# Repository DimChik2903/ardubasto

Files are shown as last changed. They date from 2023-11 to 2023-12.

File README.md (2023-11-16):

# Ardubasto: GSM/GPRS контроллер для предпусковых подогревателей с управлением по SMS и MQTT

**Автор проекта – [MaksVV](https://forum.arduino.ru/u/maksvv/) с форума arduino.ru**

[Чат в Telegram](https://t.me/ardubasto)

[Оригинальная тема](https://forum.arduino.ru/t/gsm-ustrojstvo-upravleniya-kotlami-webasto-i-ne-tolko/9851) на форуме forum.arduino.ru *При необходимости: [старая тема](https://arduino.ru/forum/proekty/gsm-ustroistvo-upravleniya-kotlami-webasto-i-ne-tolko)*

## Внимание! Репозиторий находится в разработке!

## [Основной Wiki](https://github.com/DimChik2903/ardubasto/wiki)

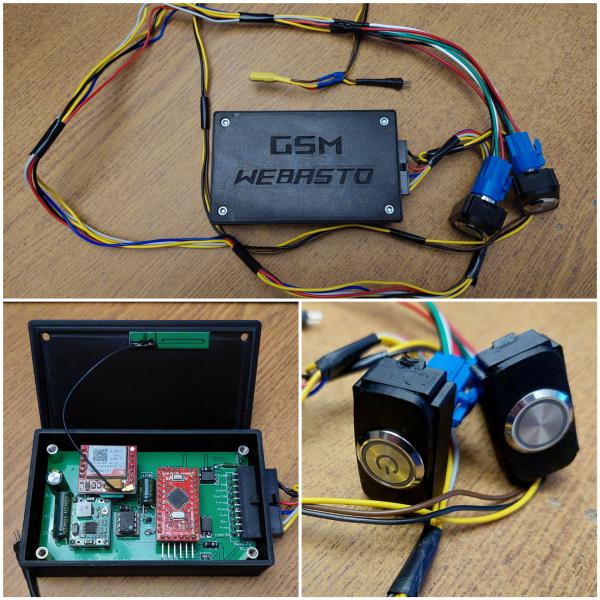
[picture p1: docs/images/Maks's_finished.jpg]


## Об устройстве
### Совместимость

* Запуск по потенциалу +12В (Webasto Thermo Top C/E)
* Запуск импульсом GND 1 сек (Webasto Thermo Top C/E)
* Запуск по шине W-Bus (Webasto Thermo Top C/E, Thermo Top Evo)
* Запуск по шине Eberspacher Hydronic

### Основные функции

* Запуск/останов котла
* Информация об ошибках
* Информация об основных параметрах котла
* Дополнительные внешние датчики температуры авто
* Работа с сигнализацеий (автозапуск)

## Быстрый старт

 [1. Закажи компоненты](https://github.com/DimChik2903/ardubasto/wiki/%D0%97%D0%B0%D0%BA%D0%B0%D0%B7-%D0%BA%D0%BE%D0%BC%D0%BF%D0%BE%D0%BD%D0%B5%D0%BD%D1%82%D0%BE%D0%B2)

 [2. Собери устройство](https://github.com/DimChik2903/ardubasto/wiki/%D0%A1%D0%B1%D0%BE%D1%80%D0%BA%D0%B0-%D1%83%D1%81%D1%82%D1%80%D0%BE%D0%B9%D1%81%D1%82%D0%B2%D0%B0)

 [3. Прошей](https://github.com/DimChik2903/ardubasto/wiki/%D0%9F%D1%80%D0%BE%D1%88%D0%B8%D0%B2%D0%BA%D0%B0)

 [4. Подключи](https://github.com/DimChik2903/ardubasto/wiki/%D0%9F%D0%BE%D0%B4%D0%BA%D0%BB%D1%8E%D1%87%D0%B5%D0%BD%D0%B8%D0%B5)

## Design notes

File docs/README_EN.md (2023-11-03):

# Ardubasto: GSM/GPRS контроллер для предпусковых подогревателей с управлением по SMS и MQTT

[English version](#ardubasto-gsmgprs-controller-for-parking-heaters-with-sms-control-and-mqtt-support)

**Автор проекта – [MaksVV](https://forum.arduino.ru/u/maksvv/) с форума arduino.ru**

[Чат в Telegram](https://t.me/ardubasto)

[Оригинальная тема](https://forum.arduino.ru/t/gsm-ustrojstvo-upravleniya-kotlami-webasto-i-ne-tolko/9851) на форуме forum.arduino.ru *При необходимости: [старая тема](https://arduino.ru/forum/proekty/gsm-ustroistvo-upravleniya-kotlami-webasto-i-ne-tolko)*

## Внимание! Репозиторий находится в разработке!

**[Основной Wiki](https://github.com/DimChik2903/ardubasto/wiki)**

## Об устройстве
### Совместимость

* Запуск по потенциалу +12В (Webasto Thermo Top C/E)
* Запуск импульсом GND 1 сек (Webasto Thermo Top C/E)
* Запуск по шине W-Bus (Webasto Thermo Top C/E)
* Запуск по шине W-Bus (Webasto Thermo Top Evo)
* Запуск по шине Бинар (?)

### Основные функции

* Запуск/останов котла
* Информация об ошибках
* Информация об основных параметрах котла
* Дополнительные внешние датчики температуры авто
* Работа с сигнализацеий (автозапуск)

## Быстрый старт

1) Заказать компоненты
2) Спаять плату
3) Прошить [eeprom](https://github.com/DimChik2903/ardubasto/tree/main/software/firmware) (eeprom)
4) Прошить [актуальную прошивку](https://github.com/DimChik2903/ardubasto/tree/main/software/firmware) (main_firmware)

# Ardubasto: GSM/GPRS controller for parking heaters with SMS control and MQTT support

**Project Author – MaksVV from arduino.ru forum**

## Attention! We are currently working on the repository!

[Wiki](https://github.com/DimChik2903/ardubasto/wiki) (In Russian)

## Fast start

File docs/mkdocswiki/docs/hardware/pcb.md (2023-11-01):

# Сборка

## Совместимость

* Запуск по потенциалу +12В (Webasto Thermo Top C/E)
* Запуск импульсом GND 1 сек (Webasto Thermo Top C/E)
* Запуск по шине W-Bus (Webasto Thermo Top Evo C)
* Запуск по шине Бинар

## Основные функции

* Запуск/останов котла
* Информация по ошибкам

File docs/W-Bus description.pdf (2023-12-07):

Описание протокола W-Bus

Supplementary heater – догреватель (предусмотрена работа только при запущенном двигателе) Auxiliary heater – догреватель
Parking heater - предпусковой подогреватель

Изменения от: 2011-01-05 (year-month-day)
Это все догадки, основанные на внешнем изучении протокола W-Bus. Никакой декомпиляции бинарников или чего то подобного не делалось.
W-Bus схематически идентичен интерфейсу OBD II. Он работает используя последовательный порт с открытым коллектором на скорости 2400 бод в формате 8E1 (с проверкой четности-even parity)

Распиновка разъемов Thermo Top V heater

8-pin разъем
Pin 1: On/Off предположительно, но не работает.

Pin 2: W-Bus (диагностика или Webasto 1533 таймер)
Pin 3: Предположительно датчик температуры для догревателя (supplemental heater)(импульсное управление «-»)
Pin 4: CAN low
Pin 5: Дозирующий топливный насос
Pin 6: Электромагнитный клапан для переключения циркуляции ОЖ Pin 7: CAN high
Pin 8: Выход управления вентилятором отопителя салона

2-pin разъем
Pin 1: +12 питания
Pin 2: Масса

3-pin разъем
Pin 1: no idea
Pin 2: +12 циркуляционной помпы Pin 3: Масса циркуляционной помпы

Примечания:
Все (большинство) числа в шестнадцатеричном виде
Поскольку RX и TX линии подключены к одной точке, все переданные данные возвращаются в передатчик Since rx and tx lines are connected together to a single wire, all
transmissions are echoed back to the transmitter.

Инициализация

//В другой документации было указано, что необходимо подать сначала логическую 1 на 25мс, а //потом логический 0 на 25мс, или наоборот.

BREAK set for 50ms
BREAK reset and wait 50ms
После этого происходит следующая передача данных, WTT опрашивает котел (функционал и идентификационные данные)

TX f4 03 51 0a ac
RX 4f 04 d1 0a 33 a3
TX f4 03 51 0b ad
RX 4f 0b d1 0b 50 51 33 35 20 53 48 20 82 TX f4 03 51 0c aa
RX 4f 0a d1 0c 71 7c c4 e7 3f 80 00 09 TX f4 02 38 ce
RX 4f 09 b8 0b 00 00 00 00 03 dd 2b

Нагреватель не отвечает без последовательности пауз (прерываний). Но не совсем понятно с какой

целью это происходит.

Протокол W-Bus основан на пакетной передаче. Передача данных это всегда сформированный пакет, с адресом, длиной, командой и контрольной суммой. Базовая структура такая:

Header, length, command, data, checksum
Заголовок, длина, команда, данные (для выполнения команды-?), контрольная сумма

Заголовок:
Включает один байт. Каждый полубайт это 4 бита адреса устройства. Высший полубайт это адрес отправителя, низший полубайт адрес получателя.
Адрес Thermo Top V heater - 4,
адрес диагностического ПО - 15,
таймер 1533 использует адрес – 3 Модуль Telestart использует адрес - 2.

Длина:
Один байт, представляющий общую сумму переданных байт.

Команда:
Обычно первый байт команды (payload-полезная нагрузка) представляет собой тип категории пакета. Она может быть представлена типом подкатегории или индексом, но не обязательно.
Когда устройство отвечает, оно посылает этот байт обратно, но MSB (старший значащий бит Most Significant Bit) устанавливается как своего рода подтверждение
When a device answers, it sends this byte back, but the MSB
is set, as some kind of acknowledge. Подкатегория, если таковая имеется, так же включена в ответ устройства.

Данные:
Любое количество байт, с одним ограничением, один байт должен использоваться для обозначения длины пакета. Обычно пакеты не длиннее 32 байт.

Контрольная сумма:
Это XOR всех байт строки.

Пример:

Клиент посылает:
0xf4 0x03 0x50 0x0f 0xa8
Заголовок: | 0xf4: Заголовок содержащий адрес
Длина | 0x03: 3 байта, включая контрольную сумму
Команда | 0x50: команда 0x50 (прочитать показания датчика) 7ой бит в команде равен нулю
Данные | 0x0f: Индекс 0x0f, то есть прочитать показания с датчиков указанных в индексе
15 (15 указано в десятеричной системе счисления, в 16ой 15=0x0f), команды 0x50.
Контрольная сумма 0xa8: (=0xf4 xor 0x03 xor 0x50 xor 0x0f)

Нагреватель отвечает:
0x4f 0x08 0xd0 0x0f 0x00 0x00 0x00 0x00 0x00 0x98

0x4f: Заголовок содержащий адрес
0x08: 8 байт, включая контрольную сумму
0xd0: Бит 7 равен 1 (подтверждение получения) команда 0x50 принята (= 0xd0 & 0x7f) 0x0f: Индекс 0x0f принят.
0x00 0x00 0x00 0x00 0x00: запрашиваемые значения
0x98: Контрольная сумма (=0x4f xor 0x08 xor 0xd0 xor 0x0f xor 0x00 xor ...0x00)

Command:
(Бит 7 равен 0 если клиент передает, 1 если нагреватель отвечает)

# Известные команды:

Команда 0x10

Выключение. Нет данных.

Команда 0x20
Включение котла. Один байт данных (время работы в минутах). Доступно только простое включение.

Команда 0x21
Включение предпускового нагревателя (parking heater). Один байт данных, время нагрева в минутах

Пример:
TX f4 03 21 3b ed
RX 4f 03 a1 3b d6

В некоторых случаях, происходит такой тип ошибки передачи данных: In some cases, this sort of NAK occurrs:
RX 4F 04 7F 21 33 26

Команда 0x22
Включить вентиляцию. Один байт данных с продолжительностью вентиляции в минутах

Пример:
TX f4 03 22 3b ee
RX 4f 03 a2 3b d5

Команда 0x23
Включить догреватель (supplemental heating). Один байт данных с продолжительностью нагрева в

минутах

Пример:
TX f4 03 23 3b ef
RX 4f 03 a3 3b d4

Команда 0x24
Внешнее управление циркуляционной помпой

Команда 0x25

Boost mode - режим ускоренного нагрева, скорее всего

Команда 0x38
Диагностика выдавала эту команду один раз. Было похоже на подтверждение. Не ясно для чего это. TX f4 02 38 ce
RX 4f 09 b8 0b 00 00 00 00 03 dd 2b

Команда 0x44
Наблюдается после каждой команды "turn on". Своего рода поддержание режима работы (keep alive). Тот же байт команды "turn on" используется для указания конкретного режима работы который сейчас запущен
Observed after any "turn on" command. It is sort of a keep alive of the
operating mode. The same command byte from the "turn on" message is used to reference that specific mode which is currently running.

Пример:
TX f4 04 44 21 00 95
RX 4f 03 c4 00 88

Похоже что нагреватель подтверждает это всегда. Неплохая идея прекратить запрос этой команды если нагреватель планируется остановить, или возможно путем считывания данных с датчика который укажет

что нагреватель остановлен. Если этого не сделать, то это может привести к бесконечному циклу работы.
If not this might cause a never ending keep alive cycle.

Команда 0x45

Тест компонентов.
Формат данных:
1 байт – индекс компонента
1: Вентилятор горелки | Combustion Fan
2: Топливный насос | Fuel Pump
3: Свеча розжига | Glow Plug
4: Циркуляционная помпа | Circulation Pump
5: Реле вентилятора автомобиля | Vehicle Fan Relays
6-8: Не используется TT-V | Not used
9: Электромагнитный клапан | Solenoid Valve
10-14: Не используется TT-V | Not used
15: Подогрев топлива | Fuel Prewarming
16: Не используется TT-V | Not used

1 байт: Время включения устройства в секундах для тестирования.
2 байта: Значение величины, в соответствии с выбранным компонентом и WBUS кодом. Процент: 2nd byte - 0.5 % равно 1 биту (2 ~> 1%).
Герц: 2nd byte - 1/20 герц равно 1 биту (20 ~> 1 Hertz).

Обороты в минуту: 1st byte MSB, 2nd byte LSB of RPM value.

Команда 0x50 «Запрос о состоянии разных систем» -мои примечания

Как я понял, запрос состоит из команды 0x50 и индекса, то есть 0x50 0x02, в ответе приходит информация о состоянии датчиков по этому запросу, запросив индекс 0x02, в ответе мы получим

статусы всех байт запросов этого индекса?

Датчики или статус запроса. Имеет один байт данных (index)

Данные: 1 байт: Possible responses below.
Heading number is the amount of bytes of the response. Номер заголовка это количество байт ответа (в ответе?)

02: Status flags (Битовые маски ниже (bitmasks below)):
byte 0 | 0x10: Запрос догревателя | Suplemental heater request
| 0x01: Главный выключатель | (Main switch)
byte 1 | 0x01: Лето | (сезон)
byte 2 | 0x10: Сигнал генератора | (Generator signal D+)
byte 3 | 0x10: Режим быстрого нагрева (boost mode)
| 0x01: Режим догревателя | (auxiliary drive)
byte 4: 0x01: Зажигание (контакт 15) (ignition (terminal 15))

03: Состояние разных подсистем (On/Off flags)

1 байт: Битовые поля компонентов (operating is signaled by bits set to 1):

0x01 Вентилятор горелки | Combustion Air Fan (CAF)
0x02 Свеча накала | Glowplug / Spark transmitter (ST)
0x04 Топливный насос | Fuel Pump
0x08 Циркуляционная помпа | Circulation Pump (CP)
0x10 Реле вентилятора автомобиля | Vehicle Fan Relay (VFR)
0x20 Подогрев сопла? | Nozzle stock heating (NSH)
0x40 Индикатор пламени | Flame indicator (FI)

04: Вид топлива, максимальное время нагрева and factor for shortening ventilation time (but details are unclear). 3 bytes. Example: 0x1d, 0x3c, 0x3c

05: Оперативные измерения (Operational measurements)

byte0: Температура со смещением 50 градусов C (20 C is value=70) byte1,2: Напряжение в милливольтах, big endian
byte3: Датчик пламени (set 0x01, not set 0x00)
byte4,5: Мощность нагрева в Ваттах, big endian
byte6,7: Сопротивление датчика пламени в миллиОмах, big endian

06: Оперативные измерения времени Operating times

byte0,1: Working hours
byte2: Working minutes
byte3,4: Operating hours
byte5: Operating minutes
byte6,7: Start counter

07: Рабочее состояние Operating state
byte0
0x00 Прожиг | Burn out
0x01 Дезактивация (Выключение?) | Deactivation
0x02 Прожиг | Burn out ADR - Australian design rules (has something
to due with hazardous substances transpotation)
0x03 Прожиг рампы | Burn out Ramp
0x04 Выключеное состояние | Off state
0x05 Горение при частичной нагрузке | Combustion process part load
0x06 Горение при полной нагрузке | Combustion process full load
0x07 Подача топлива | Fuel supply
0x08 Запуск вентилятора горелки | Combustion air fan start
0x09 Прерывание подачи топлива | Fuel supply interruption
0x0a Режим диагностики | Diagnostic state
0x0b Выключение топливного насоса? | Fuel pump interruption
0x0c EMF measurement
0x0d Debounce
0x0e Дезактивация (Выключение?) | Deactivation
0x0f Опрос датчика пламени | Flame detector interrogation
0x10 Охлаждение датчика пламени | Flame detector cooling
0x11 Режим измерения датчика пламени Flame detector measuring phase
0x12 | Flame detector measuring phase ZUE
0x13 Включение вентилятора | Fan start up
0x14 Glow plug ramp
0x15 Нагреватель заблокирован? | Heater interlock
0x16 Инициализация | Initialization
0x17 Компенсация воздуха в топливе | Fuel bubble compensation
0x18 Холодный запуск вентилятора? | Fan cold start-up
0x19 | Cold start enrichment
0x1a Охлаждение | Cooling
0x1b Load change PL-FL
0x1c Вентиляция | Ventilation
0x1d Load change FL-PL
0x1e New initialization
0x1f Controlled operation
0x20 Control iddle period
0x21 Мягкий старт | Soft start
0x22 Savety time
0x23 Чистка | Purge
0x24 Старт | Start
0x25 Стабилизация | Stabilization
0x26 Start ramp
0x27 Out of power
0x28 Блокировка | Interlock
0x29 Блокировка | Interlock ADR (Australian design rules)
0x2a Время стабилизации | Stabilization time
0x2b Change to controlled operation
0x2c Decision state
0x2d Подкачка топлива перед стартом Prestart fuel supply 0x2e Glowing
0x2f Glowing power control
0x30 Delay lowering
0x31 Sluggish fan start
0x32 Additional glowing
0x33 Ignition interruption 0x34 Ignition
0x35 Intermittent glowing

0x36 Application monitoring
0x37 Interlock save to memory 0x38 Heater interlock deactivation 0x39 Output control
0x3a Circulating pump control 0x3b Initialization uP
0x3c Stray light interrogation 0x3d Prestart
0x3e Pre-ignition
0x3f Flame ignition
0x40 Flame stabilization
0x41 Combustion process parking heating 0x42 Combustion process suppl. heating 0x43 Combustion failure failure heating 0x44 Combustion failure suppl. heating 0x45 Heater off after run
0x46 Control iddle after run
0x47 After-run due to failure
0x48 Time-controlled after-run due to failure 0x49 Interlock circulation pump
0x4a Control iddle after parking heating
0x4b Control iddle after suppl. heating
0x4c Control iddle period suppl. heating with circulation pump 0x4d Circulation pump without heating function
0x4e Waiting loop overvoltage
0x4f Fault memory update
0x50 Waiting loop
0x51 Component test
0x52 Boost
0x53 Cooling
0x54 Heater interlock permanent 0x55 Fan iddle
0x56 Break away
0x57 Temperature interrogation 0x58 Prestart undervoltage 0x59 Accident interrogation
0x5a After-run solenoid valve
0x5b Fault memory update solenoid valve
0x5c Timer-controlled after-run solenoid valve 0x5d Startup attempt
0x5e Prestart extension
0x5f Combustion process
0x60 Timer-controlled after-run due to undervoltage 0x61 Fault memory update prior switch off
0x62 Ramp full load
byte1 Operating state state number
byte2 Device state bit field 0x01 STFL
0x02 UEHFL
0x04 SAFL
0x08 RZFL
byte3,4,5: Unknown

10: burning duration, PH, SH, at power levels 0.33,34..66,67..100,>100 each 11: Working duration PH (park heating) and SH (supplemental heating)
12: Start counters
byte0,1 PH start counter
byte2,3 SH start counter
byte4,5 TRS counter (Territories and Regional Support ? Thermal Reed Switch ?)

15: Subsystems status
byte0: Glow plug power in percent *2 byte1: Fuel pump pulse frequency in Hz *2 byte2: Combustion air fan in percent*2

byte3:
byte4: Circulation pump percent*2

17: Верхний и нижний температурные пороги (50C offset one unsigned byte each)

18: Время работы вентиляции (2bytes hours big endian and one byte
minutes, just like all other time values)

19: Fuel prewarming status
2 bytes: Fuel prewarming PTC resistance in mili ohm, big endian 2 bytes: Fuel prewarming power in watts

20: spark transmision

Command 0x51 read stuff
Index 0x01: Device ID Number
Index 0x02: Hardware version (KW/Year), Software version, Software version EEPROM

Index 0x03: Data Set ID Number
Index 0x04: Control Unit Herstellungsdatum (Tag monat jahr je ein byte)
Index 0x05: Heater manufacture date (Day of month, month, year. Each one byte) Index 0x06: 1 byte, no idea
Index 0x07: Customer ID Number (i.e. VW Part number)
Index 0x09: Serial Number

Index 0x0a: W-BUS version. 1 byte, each nibble is one digit. 0x33 means version 3.3

Index 0x0b: Device Name: ASCII Text string.
Index 0x0c: W-BUS code. Flags of supported subsystems (bitmasks below). byte0
0x01 unknown (ZH)
0x08 Simple on/off control

0x10 Parking heating
0x20 Supplemental heating
0x40 Ventilation
0x80 Boost mode
byte1
0x02 External circulation pump control 0x04 Combustion air fan (CAV)
0x08 Glow Plug (flame detector)
0x10 Fuel pump (FP)
0x20 Circulation pump (CP) 0x40 Vehicle fan relay (VFR) 0x80 Yellow LED
byte2
0x01 Green LED present
0x02 Spark transmitter. Implies no Glow plug and thus no resistive flame detector. 0x04 Solenoid valve present (coolant circuit switching)
0x08 Auxiliary drive indicator (whatever that means)
0x10 Generator signal D+ present
0x20 Combustion air fan level is in RPM instead of percent 0x40 (ZH)
0x80 (ZH)
byte3
0x02 CO2 calibration
0x08 Operation indicator (OI) byte4
0x0f (ZH)
0x10 Heating energy is in watts (or if not set in percent and the value field must be divided
by 2 to get the percent value)
0x20 (ZH)
0x40 Flame indicator (FI)
0x80 Nozzle Stock heating
byte5

0x80 Fuel prewarming resistance and power can be read.
0x40 Temperature thresholds available, command 0x50 index 0x11 (whatever that means) 0x20 Ignition (T15) flag present
byte6
0x02 Set value flame detector resistance (FW-SET), set value combustion air fan revolutions

(BG-SET), set value output temperature (AT-SET)

Index 0x0d: No idea.

Command 0x52 сброс ошибок (используется без операндов)

Command 0x53:
Read other kind of data. Seemingly rather static data. Diagnosis does not do this so often. TX f4 03 53 02 a6
RX 4f 11 d3 02 2c 24 25 1c 30 d4 fa 40 74 00 00 63 9c 05 6e
bytes:
0: | Неизвестно
1,2: | Порог минимального напряжения | Minimum Voltage threshold
3,4,5,6: | Неизвестно
7: | Minimum voltage detection delay (delay)
8,9: | Порог максимального напряжения | Maximum voltage threshold
10,11,12,13: Неизвестно
14: | Max voltage detection delay (seconds)

Command 0x56

Команды для работы с кодами ошибок
First byte serves as an index as follows:

Index 01: read error code list. No Data. Answer ist the error code list using the following format:
byte: Amount of error codes. That amount of times, there are the following bytes:
byte: Error code numerical value.
byte: Error code count-1 (how many time the failure condition was triggered until now).

Example:
TX f4 03 56 01 a0
RX 4f 0a d6 01 03 98 00 88 00 90 00 11

Error codes:
0x01 Defective control unit 0x02 No start
0x03 Flame failure
0x04 Supply voltage too high
0x05 Flame was detected prior to combustion 0x06 Heating unit overheated
0x07 Heating unit interlocked
0x08 Metering pumpu short circuit
0x09 Combustion air fan short circuit 0x0a Glow plug/flame monitor short circuit

0x0b Circulation pump short circuit
0x0c No comunication to air condition 0x0d Green LED short circuit
0x0e Yellow LED short circuit
0x0f No configuraton signal 0x10 Solenoid valve short circuit 0x11 ECU wrong coded
0x12 W-Bus comunication failure 0x13 Vehicle fan relay short circuit 0x14 Temperature sensor short circuit 0x15 Combustion air fan blocked
0x16 Battery main switch short circuit

0x17 Invalid air flow reduction
0x18 Comunication failure on customer specific bus 0x19 Glow plug/electronic ignition short circuit

0x1a Flame sensor short circuit
0x1b Overheat short circuit
0x1c Fault 28
0x1d Solenoid valve shed test short circuit 0x1e Fuel sensor short circuit
0x1f Nozzle stock heating short circuit 0x20 Operation indicator short circuit 0x21 Flame indicator short circuit 0x22 Reference resistance wrong
0x23 Crash interlock activated 0x24 Car is almost out of fuel
0x25 Fuel pre heating short circuit 0x26 PCB temperatur sensor short circuit
0x27 Ground contact to the ECU broken
0x28 Board net energy manager low power voltage 0x29 Fuel priming still not done
0x2a Error in the radio telegram
0x2b Telestart still not programmed
0x2c The pressure sensor has short circuit 0x2d Fault 45
0x31 Fault 49
0x32 No start from control idle period 0x33 Flame monitor signal invalid
0x34 Default values entered
0x35 EOL programming has not been carried out 0x36 Thermal fuse short circuit
0x37 Fault 55
0x4f Fault 79
0x50 User interface idle-Mode (no-communication) 0x51 User interface has communication fault
0x52 User interface send no defined operating mode 0x53 Heater fan status message negative
0x54 Heater fan status bus has short circuit to UB 0x55 Temperature water sensor failure
0x56 Temperature water sensor short circuit to UB 0x57 Overheating water temperature sensor
0x58 Overstepping water temperature sensor gradient 0x59 Overheating blow temperature sensor
0x5a Overstepping low temperature sensor gradient
0x5b Overheating printed circuit board temperature sensor 0x5c Overstepping printed circuit board temp sensor gradient 0x5d Cabin temperature sensor failure
0x5e Flame detector gradient failure
0x5f Emergency cooling
0x60 Customer specific fault 1
0x7f Customer specific fault 32 0x80 Fault 128
0x81 EOL checksum error
0x82 No start during test-run 0x83 Flame failure
0x84 Operating voltage too low
0x85 Flame was detected after combustion 0x86 Fault 134
0x87 Heater lock-out permanent
0x88 Fuel pump failure
0x89 Combustion air fan interruption
0x8a Glow plug / flame monitor interruption

0x8b Circulation pump interruption

0x8c Fault 140
0x8d Green LED interruption 0x8e Yellow LED interruption 0x8f Fault 143
0x90 Solenoid valve interruption
0x91 Control unit locked or coded as neutral 0x92 Command refresh failure
0x93 Fault 147
0x94 Temperature sensor interruption 0x95 Combustion air fan tight
0x96 Fault 150
0x97 Overheat sensor position wrong
0x98 Fault 152 (Power supply interruption)
0x99 Glow plug / electronic ignition unit interruption

0x9a Flame sensor interruption
0x9b Setpoint transmitter invalid
0x9c Intelligent undervoltage detection 0x9d Solenoid valve shed test interruption 0x9e Fuel sensor interruption
0x9f Nozzle stock heating interruption 0xa0 Operating indicator interruption 0xa1 Flame indicator interruption 0xa2 Fault 162
0xa4 Fault 164
0xa5 Fuel pre heating interruption 0xa6 PCB temperature sensor interruption
0xa7 Fault 167
0xa8 Communication board net energy manager error 0xa9 Fault 169
0xaa Send on W-Bus not succeed
0xab Overheat sensor interruption 0xac The pressure sensor failure 0xad Fault 173
0xb5 Fault 181
0xb6 Thermal fuse interrupted 0xb7 Fault 183
0xd0 Fault 208
0xe0 Customer specific fault 33
0xfe Customer specific fault 63 0xff Unknown error code

Index 02: Read complete error code block. 1 data byte corresponding to the error code numerical value.
Format:
5 bytes: comprises status, counter, temperature, etc.

1 byte status flags
0x01 stored
0x02 actual
1 byte counter
2 bytes operating state as command 0x50 index 7 byte 0,1
1 byte Temperatur in Celcius offset 50 degree (value 70 -> 20 degrees) 2 bytes: Power supply voltage during the incident in mili volt.
2 bytes: Operating duration hours at the incident
1 byte: Operating duration minutes at the incident

Example transaction
TX f4 04 56 02 98 3c
RX 4f 0e d6 02 98 03 06 04 00 46 35 66 03 97 37 ba

Error code count: 1

Error code 98, counter: 1
State: 3
Counter: 6
Unkown values 4 0
Temperatur 20 C
Power supply tension: 0.870000 Operating time: 14231:234

State: Not actual, not stored Counter 1
Temperature 20 degrees Celcius Operating State Off

Some more examples
TX f4 04 56 02 98 3c
RX 4f 0e d6 02 98 00 01 04 00 46 35 66 03 97 1b 92 TX f4 04 56 02 88 2c
RX 4f 0e d6 02 88 00 01 04 00 46 35 7a 03 97 1d 98 TX f4 04 56 02 90 34
RX 4f 0e d6 02 90 00 01 04 00 46 35 66 03 97 1d 9c

Index 03: Стереть коды ошибок. No data.

Command 0x57: Калибровка CO2

example:
TX f4 03 57 01 a1
RX 4f 06 d7 01 | 97 64 ff | 93

index 1 Прочитать калибровочное значение CO2 (one byte each: current, minimum, maximum) index 3 Записать калибровочное значение CO2 (one byte)

IDs of some devices

Label sticker: 1K0 815 005FR (does not match value read out below) W-Bus version: 3.3
Device Name: PQ46 SH
W-Bus code: 717cc4e73f8000 Device ID Number: 090115594a Data set ID Number: 090133974100 Software ID Number: 0000000030 Hardware version: 37/4
Software version: Friday 13/5 | 5.61
Software version EEPROM: Friday 13/5 | 5.61

Date of Manufacture Control Unit: 26.10.5 Date of Manufacture Heater: 7.11.5 Customer ID Number: 1K0815007AP3602 Serial Number: 0000025118
Sensor8: 41f0e004080400
U1: 0b0000000003dd
System Level: 00

W-Bus version: 3.3
Device Name: PQ35 ZH
W-Bus code: 213cc0e73f0000 Device ID Number: 0900620743 Data set ID Number: 090074764500 Software ID Number: 0000000030 Hardware version: 38/2
Software version: Monday 16/3 | 4.7
Software version EEPROM: Monday 16/3 | 4.7

Date of Manufacture Control Unit: 14.9.3

Date of Manufacture Heater: 1.10.3 Customer ID Number: 1K0815071E 0707 Serial Number: 0000349144
Sensor8: 420975b7000000
U1: 0b0000000003bf

System Level: 75

Some Software version (from elektroda.pl) 1K0 815 007CD, SW: 4709
1K0 815 005JT, SW: 4707
1K0 815 005JT, SW: 4707
1K0 815 005JJ, SW: 4404
1K0 815 005JJ, SW: 4404
1K0 815 005JD, SW: 4404
1K0 815 007BH, SW: 4404
3C0 815 005AB, SW: 4401
1K0 815 007BT, SW: 3907
1K0 815 007BG, SW: 3803
1K0 815 005DR, SW: 1706
1K0 815 005GT, SW
1K0 815 005FR, SW: 1305
1K0 815 007AM, SW: 4804
1K0 815 071E, SW: 1603

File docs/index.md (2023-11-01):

# Об устройстве

## Совместимость

* Запуск по потенциалу +12В (Webasto Thermo Top C/E)
* Запуск импульсом GND 1 сек (Webasto Thermo Top C/E)
* Запуск по шине W-Bus (Webasto Thermo Top Evo C)
* Запуск по шине Бинар

## Основные функции

* Запуск/останов котла
* Информация по ошибкам

 Актуальная версия платы

 - Актуальный скетч подготовки еепром и основной скетч - смотрим в этой папке последнюю версию. В скетче еепром делаем предварительные настройки (в комментах всё подробно там).  Сначала заливаем скетч еепром, дожидаемся пока загорится встроенный светодиод LED 13. Потом заливаем основной скетч. Там же в папке актуальная инструкция пользователя. 

- список деталей и рассыпухи для заказа

- корпус девайса на 3д принтере

- Для удобства отправки СМС команд рекомендую использовать приложение для Андройид GSM Trinket. (качается в playMarket). Файл настроек брелка для программы GSM Trinket. Подробности читаем в инструкции к моему устройству. Но когда появился MQTT это уже лишнее, хотя как резервный вариант всетаки лучше иметь, чтобы не вспоминать команды управления, в случае отказа облачного сервиса MQTT.

- Настройка MQTT на смартфоне тут. MQTT для тех кто не знает - это текстовый протокол взаимодействия, в нашем случае управление по интернет соединению, т.к. через облачный сервер. Работает почти в реальном времени, т.е. мгновенный отклик и дешевле СМС. В месяц трафик не более 10 Мб. 

- Для тех кто будет подключать сигнализацию старлайн: 

В таблице программирования AF сигнализации Starline необходимо запрограммировать следующие функции (помечены красными галочками): Это всё справедливо для сигнализаций B94, D94, E90, E91. Для A94 будет немного отличаться, надо корректировать номера доп.каналов. 

Далее на доп.каналы настраиваем следующие события включения и задержки:

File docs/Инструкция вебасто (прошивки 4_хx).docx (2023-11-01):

Работа устройства через СМС сообщения

Управление устройством осуществляется при помощи СМС и возможно только с номеров телефонов, сохранённых в памяти. Изначально в памяти устройства не записаны номера телефонов пользователей. Устройство при этом отвечает только на три СМС команды (писать без кавычек!!!):

1. «Zapros» - проверка работоспособности устройства.

2. «Zaprostel» - запрос номеров телефонов, записанных в память устройства.

Если в ответной СМС на этот запрос номера телефонов будут вида «000000000000» или «яяяяяяяяяяяя», то номера телефонов не записаны в память устройства.

3. «WriteNumber1» - после посылки СМС с таким текстом на устройство, происходит запись номера телефона (с которого это СМС отправлено) в память как номер #1.

После записи номера #1 в память, на этот телефон приходит подтверждающее СМС.

Как только произведена запись номера #1 в память, становится возможным управление устройством в полном функционале.

Для записи номера #2 необходимо с номера #1 отправить СМС с текстом «WriteNumber2».

После отправки данной команды приходит подтверждающее СМС, в котором указано, что нужно отправить СМС с любым текстом с номера#2 для его сохранения в память.

Теперь, если отправлено любое СМС с номера #2, он сохраняется в памяти, приходит подтверждающее СМС.

Управление с номера #2 полностью аналогично управлению с номера #1, за исключением того, что удаление номеров из памяти и запись номера #2 возможно лишь с номера #1.

Список СМС команд управления устройством (текст команд должен строго соответствовать – пробелы, тире, регистр букв (заглавная или прописная) и т.д. – команду писать без кавычек!!! ):

1. «Zapros» - запрос на предоставление текущего состояния всех параметров устройства .
2. «Zaprostel» - запрос на предоставление телефонных номеров пользователей, сохранённых в памяти.
3. «Service-info» - запрос на предоставление сервисной информации устройства (протокол запуска подогревателя, протокол чтения статусов подогревателя, тип подогревателя, количество рестартов GSM модуля, величина delta - разница температур улицы и выхлопа, при которой считается, что котёл успешно запущен, если статусы по шине, то ошибки и некоторые текущие параметры котла). Если в ответной смс видим напротив параметров надпись No Data – значит котёл не ответил
4. «Version» - запрос версии прошивки устройства
5. «Heater-ON» - включение подогревателя
6. «Heater-OFF»- выключение подогревателя
7. «Engine-ON» - команда на запуск двигателя сигнализацией
8. «Engine-OFF» - команда на остановку двигателя сигнализацией
9. «Balance» - запрос баланса симкарты.

Ниже идёт выбор протокола, по которому будет осуществляться запуск подогревателя:

10. «Impulse» - запуск подогревателя осуществляется 1-секундным импульсом «массы»
11. «Startbus» - запуск подогревателя осуществляется цифровым сигналом по шине
12. «Potencial» - запуск подогревателя осуществляется потенциалом +12В

Ниже идёт выбор протокола чтения статусов подогревателя

13. «Status BUS» – чтение статусов по цифровой шине
14. «Status Analog» – чтение статусов при помощи температурных датчиков девайса (аналог)

Ниже идёт выбор типа цифровой шины подогревателя

15. «HeaterBusType TTC_E» тип шины: Thermo Top C/E (K_LINE 10400 8N1)
16. «HeaterBusType W-BUS» тип шины: W-BUS (W_BUS 2400 8E1)
17. «HeaterBusType Hydronic» тип шины: Hydronic (K_LINE 1200 8N1)
18. «min x» - вместо x подставляем нужное время работы подогревателя в минутах (используется только для протоколов запуска Startbus и Potencial)
19. «Delta x» - вместо x подставляем нужную разницу температур улицы и выхлопа , превышая которую считается, что подогреватель запустился успешно (используется в случае, если протокол чтения статусов подогревателя: по аналогу Status Analog)
20. «StartByte x» - вместо x подставляем нужный байт для старта подогревателя (используется только для подогревателей с шиной W-bus). х может принимать только три значения:

20, 21 или 23

21. «ResetNumbers» - после отправки данной команды номера стираются из памяти (работает только с номера #1).
22. «GSMResets» - данная команда сбрасывает счётчик рестартов GSM модуля
23. «MQTT-reset» - данная команда перезагружает работу устройства по MQTT (интернет соединение)
24. «xx xx xx xx xx xx xx xx yy address» - данная команда позволяет прописать новый адрес датчика даллас DS18B20 в память устройства.

Вместо xx xx xx xx xx xx xx xx подставляем адрес датчика в HEX числах (между числами по одному пробелу!)

Вместо yy подставляем число, соответствующее определённой температуре :

00 – датчик температуры выхлопа

01 – датчик температуры двигателя

02 – датчик температуры улицы

03 – датчик температуры салона

Пример сообщения для сохранения нового адреса датчика температуры двигателя:

28 FF D3 E2 C1 17 04 0D 01 address

где жирным шрифтом – адрес датчика, нежирным – остальной текст сообщения.

В случае успешной записи адреса датчика устройство пришлёт соответствующий отчет с адресами всех датчиков. В противном случае в отчете будет информация об ошибке записи.

25. «DallasAddr» - запрос на предоставление всех адресов датчиков температуры даллас DS18B20.
26. «Erase DTC» - запрос стирания кодов неисправности подогревателя. На некоторых подогревателях этой же командой снимается и блокировка.

После отправки команды «Heater-ON» приходит оповещение, что команда принята, а через 6 мин приходит отчет – удачно ли произошел старт подогревателя.

После отправки команды «Engine-ON» приходит оповещение, что команда принята, а через 1,5 минуты приходит отчет – удачно ли произошел старт двигателя.

Если сигнализация на охране и включилась тревога (сирена кричит) – приходит соответствующее СМС на оба номера.

Номера телефонов, время работы подогревателя, протокол запуска и чтения статусов подогревателя и другие настраиваемые параметры хранятся в энергонезависомой памяти устройства и сохраняются после перевключения питания.

Для удобства управления устройством при помощи СМС команд (чтобы каждый раз не вводить команды) необходимо скачать с PlayMarket приложение «GSM Trinket». Скачиваем файл настроек брелка, идущий в комплекте с устройством, на телефон. Открываем приложение – настройки – настройки брелков – справа вверху кнопка восстановление настроек брелка – выбираем скаченный файл настроек брелка. Выходим в общий вид программы. Листая вправо-влево, выбираем созданный только что брелок. Заходим в настройки, убираем галочку «Отчет о доставке», заходим в настройки брелков, выбираем наш брелок – «правка» - входящие сообщения- убираем галочку (если установлена) «Перехватывать входящие сообщения». Программа готова к работе.

Управление системой через интернет при помощи сервиса MQTT.

На смартфоне необходимо через Google Play скачать приложение MQTT Dash. Далее нужно создать аккаунт на MQTT сервере (брокере) cloudmqtt.com или clusterfly.ru. После регистрации брокер выдаст настройки сервиса:

1. Адрес сервера.
2. Порт.
3. логин (username).
4. пароль (password).

Эти данные необходимо указать в прошивке (вверху скетча) при программировании устройства.

Также эти данные нужно указать в приложении MQTT Dash.

Панель управления MQTT Dash представляет собой набор плиток (так называемых метрик).

При выключенном подогревателе автоматически обновляются раз в 2 минуты только две метрики «Управление котлом» и «Уровень сигнала GSM». Для обновления информации остальных метрик необходимо нажать на плитку «Обновить данные». При взаимодействии девайса с котлом по цифровой шине некоторые метрики обновляются не сразу. После нажатия на «Обновить данные» сначала появляется надпись wait (перевод ждите ) , далее, через несколько секунд, в случае успешной связи с котлом, можно наблюдать актуальные параметры, а в случае неудачной связи по каким-либо причинам – надпись fail.

При включенном подогревателе все метрики обновляются автоматически раз в 30 секунд.

При нажатии на плитку «Установить время цикла» происходит выбор времени цикла работы подогревателя.

При нажатии на плитку «Количество ошибок/удалить» происходит удаление кодов неисправностей подогревателя, а на некоторых и снимается блокировка, если котел в ней находился.

При нажатии на плитку «Число рестартов модема» происходит сброс счетчика рестартов модема.

Подключение датчиков температуры

Подключение датчиков температуры DS18B20 производить параллельно.

Изначально адреса датчиков температуры, идущих в комплекте с устройством, уже записаны в память устройства и места установки датчиков промаркированы на них.

При замене датчика возможно записать новый его адрес в память устройства. Для этого необходимо заранее узнать адрес нового датчика, подключив пример библиотеки работы с датчиками даллас, используя сериал монитор. Также необходимо естественно пометить новый датчик куда он будет установлен - ДВС, улица, выхлоп подогревателя или салон.

Далее сохранить адреса новых датчиков в память устройства (см. выше соответствующую СМС команду).

Если, при работе устройства, будет получена та или иная температура, равная -101 градус, это говорит о неправильном считывании температуры от этого конкретного датчика. Причиной тому может быть :

- некорректный сохранённый адрес датчика;

- неисправности в эл.проводке и/или подключении;

- отказ датчика.

Вид со стороны проводов разъёма.

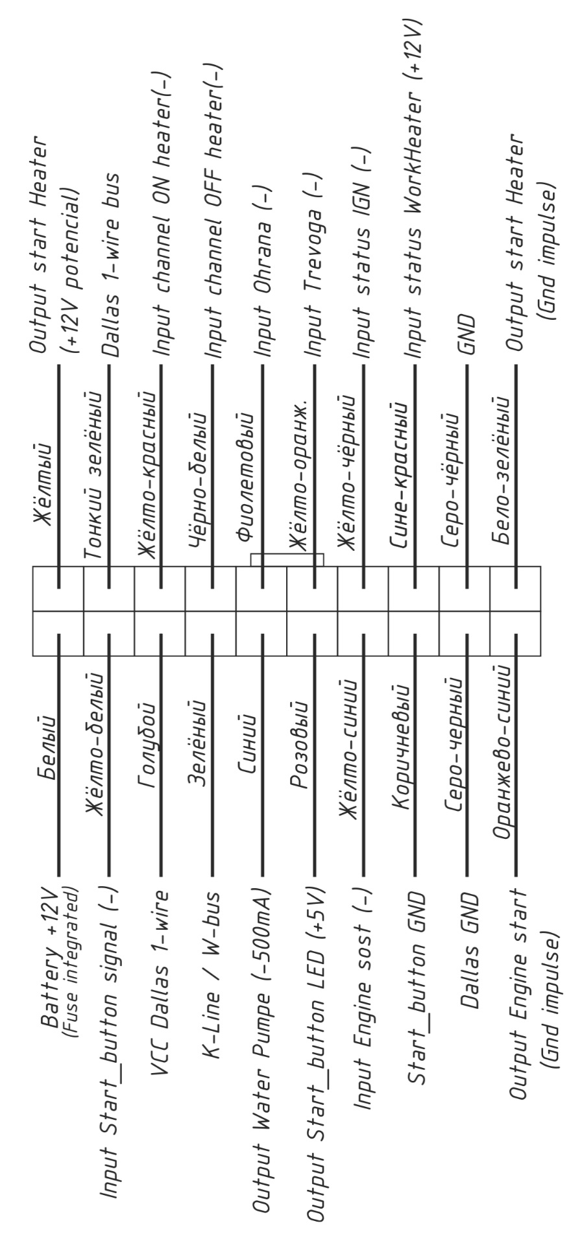
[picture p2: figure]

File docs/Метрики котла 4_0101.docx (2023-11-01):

[{"iconOff":"ic_power_settings_new","iconOn":"ic_power_settings_new","offColor":-1,"onColor":-12550144,"payloadOff":"0\u0026$","payloadOn":"1\u0026$","enableIntermediateState":true,"enablePub":true,"enteredIntermediateStateAt":0,"intermediateStateTimeout":8,"jsOnReceive":"","jsonPath":"","lastPayload":"0\u0026$","qos":0,"retained":false,"topic":"s/hea","topicPub":"c/hea","updateLastPayloadOnPub":false,"id":"5ffcabe0-f5f1-41d1-85ba-6b6ed51516ba","jsBlinkExpression":"","jsOnDisplay":"","jsOnTap":"","lastActivity":1607436537,"longId":1,"name":"Управление котлом ","type":2},{"iconOff":"ic_fire_01","iconOn":"ic_fire_01","offColor":-1,"onColor":-65536,"payloadOff":"0","payloadOn":"1","enableIntermediateState":true,"enablePub":false,"enteredIntermediateStateAt":0,"intermediateStateTimeout":0,"jsOnReceive":"","jsonPath":"","lastPayload":"0","qos":0,"retained":false,"topic":"s/fla","topicPub":"","updateLastPayloadOnPub":true,"id":"d93aae84-ebef-428a-8ddb-fb6a38319c15","jsBlinkExpression":"","jsOnDisplay":"","jsOnTap":"","lastActivity":1607436537,"longId":5,"name":"Состояние пламени","type":2},{"mainTextSize":"LARGE","postfix":"°","prefix":"","textColor":-16384,"enableIntermediateState":true,"enablePub":false,"enteredIntermediateStateAt":0,"intermediateStateTimeout":0,"jsOnReceive":"","jsonPath":"","lastPayload":"-101","qos":0,"retained":false,"topic":"s/t/v","topicPub":"","updateLastPayloadOnPub":true,"id":"c4476183-0093-4d20-8800-250a604ab522","jsBlinkExpression":"","jsOnDisplay":"","jsOnTap":"","lastActivity":1607436537,"longId":18,"name":"Температура выхлопа","type":1},{"mainTextSize":"LARGE","postfix":"","prefix":"","textColor":-16744193,"enableIntermediateState":true,"enablePub":false,"enteredIntermediateStateAt":0,"intermediateStateTimeout":0,"jsOnReceive":"","jsonPath":"","lastPayload":"выкл","qos":1,"retained":false,"topic":"s/rti","topicPub":"","updateLastPayloadOnPub":false,"id":"33324200-a8e6-49d6-a2f0-64db72375ba8","jsBlinkExpression":"","jsOnDisplay":"","jsOnTap":"","lastActivity":1607436537,"longId":4,"name":"Оставшееся время работы котла, мин","type":1},{"items":[{"label":"15 мин","payload":"15\u0026$"},{"label":"20 мин","payload":"20\u0026$"},{"label":"30 мин","payload":"30\u0026$"},{"label":"45 мин","payload":"45\u0026$"},{"label":"1 час","payload":"59\u0026$"}],"mainTextSize":"LARGE","textColor":-16129,"enableIntermediateState":true,"enablePub":true,"enteredIntermediateStateAt":0,"intermediateStateTimeout":10,"jsOnReceive":"","jsonPath":"","lastPayload":"30","qos":0,"retained":false,"topic":"s/tim","topicPub":"c/tim","updateLastPayloadOnPub":false,"id":"117d0c7d-2b4c-4216-babc-e29fd5d2102a","jsBlinkExpression":"","jsOnDisplay":"","jsOnTap":"","lastActivity":1607436537,"longId":10,"name":"Установить время цикла, мин","type":4},{"mainTextSize":"LARGE","postfix":"°","prefix":"","textColor":-16384,"enableIntermediateState":true,"enablePub":false,"enteredIntermediateStateAt":0,"intermediateStateTimeout":0,"jsOnReceive":"","jsonPath":"","lastPayload":"23","qos":0,"retained":false,"topic":"s/t/h","topicPub":"","updateLastPayloadOnPub":true,"id":"14197aca-5048-4d40-a2e2-b1222087e847","jsBlinkExpression":"","jsOnDisplay":"","jsOnTap":"","lastActivity":1607436540,"longId":6,"name":"Температура котла","type":1},{"mainTextSize":"LARGE","postfix":"°","prefix":"","textColor":-16384,"enableIntermediateState":true,"enablePub":false,"enteredIntermediateStateAt":0,"intermediateStateTimeout":0,"jsOnReceive":"","jsonPath":"","lastPayload":"-101","qos":0,"retained":false,"topic":"s/t/u","topicPub":"","updateLastPayloadOnPub":true,"id":"9c4dc9bd-db9e-48d7-964b-1f9bf64ef219","jsBlinkExpression":"","jsOnDisplay":"","jsOnTap":"","lastActivity":1607436537,"longId":7,"name":"Температура улицы","type":1},{"mainTextSize":"LARGE","postfix":"°","prefix":"","textColor":-16384,"enableIntermediateState":true,"enablePub":false,"enteredIntermediateStateAt":0,"intermediateStateTimeout":0,"jsOnReceive":"","jsonPath":"","lastPayload":"-101","qos":0,"retained":false,"topic":"s/t/s","topicPub":"","updateLastPayloadOnPub":true,"id":"12508932-d062-47f6-8c63-3ea8f457a758","jsBlinkExpression":"","jsOnDisplay":"","jsOnTap":"","lastActivity":1607436537,"longId":8,"name":"Температура салона","type":1},{"mainTextSize":"LARGE","postfix":"°","prefix":"","textColor":-16384,"enableIntermediateState":true,"enablePub":false,"enteredIntermediateStateAt":0,"intermediateStateTimeout":0,"jsOnReceive":"","jsonPath":"","lastPayload":"-101","qos":0,"retained":false,"topic":"s/t/d","topicPub":"","updateLastPayloadOnPub":true,"id":"8d0ba876-9a4f-4045-8af4-db131043ecf8","jsBlinkExpression":"","jsOnDisplay":"","jsOnTap":"","lastActivity":1607436537,"longId":2,"name":"Температура двигателя","type":1},{"mainTextSize":"LARGE","postfix":"","prefix":"","textColor":-4128960,"enableIntermediateState":true,"enablePub":false,"enteredIntermediateStateAt":0,"intermediateStateTimeout":0,"jsOnReceive":"","jsonPath":"","lastPayload":"wait","qos":0,"retained":false,"topic":"s/nap","topicPub":"","updateLastPayloadOnPub":true,"id":"3fbac020-95f7-4643-84e8-4c4936737699","jsBlinkExpression":"","jsOnDisplay":"","jsOnTap":"","lastActivity":1607436537,"longId":12,"name":"Напряжение бортовой сети, В","type":1},{"mainTextSize":"LARGE","postfix":"","prefix":"","textColor":-4194240,"enableIntermediateState":true,"enablePub":false,"enteredIntermediateStateAt":0,"intermediateStateTimeout":0,"jsOnReceive":"","jsonPath":"","lastPayload":"wait","qos":0,"retained":false,"topic":"s/pow","topicPub":"","updateLastPayloadOnPub":true,"id":"929719e8-0115-4c89-b3c0-44b0004446cc","jsBlinkExpression":"","jsOnDisplay":"","jsOnTap":"","lastActivity":1607436537,"longId":14,"name":"Мощность горения, %","type":1},{"mainTextSize":"LARGE","postfix":"","prefix":"","textColor":-65344,"enableIntermediateState":true,"enablePub":false,"enteredIntermediateStateAt":0,"intermediateStateTimeout":0,"jsOnReceive":"","jsonPath":"","lastPayload":"wait","qos":0,"retained":false,"topic":"s/dtc","topicPub":"","updateLastPayloadOnPub":true,"id":"3ba386e0-ded5-402d-be29-7e04dee2d12e","jsBlinkExpression":"","jsOnDisplay":"","jsOnTap":"","lastActivity":1607436537,"longId":15,"name":"Количество ошибок котла","type":1},{"iconOff":"ic_loop_black","iconOn":"ic_loop_black","offColor":-4128896,"onColor":-4128896,"payloadOff":"0\u0026$","payloadOn":"1\u0026$","enableIntermediateState":false,"enablePub":true,"enteredIntermediateStateAt":0,"intermediateStateTimeout":0,"jsOnReceive":"","jsonPath":"","qos":0,"retained":false,"topic":"","topicPub":"c/ref","updateLastPayloadOnPub":false,"id":"e217b0fb-4ba4-4a3a-addb-37312fcc9c61","jsBlinkExpression":"","jsOnDisplay":"","jsOnTap":"","lastActivity":0,"longId":11,"name":"Обновить данные","type":2},{"mainTextSize":"LARGE","postfix":"","prefix":"","textColor":-16760640,"enableIntermediateState":true,"enablePub":false,"enteredIntermediateStateAt":0,"intermediateStateTimeout":0,"jsOnReceive":"","jsonPath":"","lastPayload":"26","qos":0,"retained":false,"topic":"s/lev","topicPub":"","updateLastPayloadOnPub":true,"id":"ba3a84d1-e4ca-4aff-9690-7e0f2bab59e0","jsBlinkExpression":"","jsOnDisplay":"","jsOnTap":"","lastActivity":1607436537,"longId":17,"name":"Уровень сигнала GSM","type":1},{"items":[{"label":"сброс","payload":"0\u0026$"}],"mainTextSize":"LARGE","textColor":-16727809,"enableIntermediateState":true,"enablePub":true,"enteredIntermediateStateAt":0,"intermediateStateTimeout":8,"jsOnReceive":"","jsonPath":"","lastPayload":"87","qos":0,"retained":false,"topic":"s/res","topicPub":"c/Res","updateLastPayloadOnPub":false,"id":"1368a101-7da0-448f-864b-2f401f1e270d","jsBlinkExpression":"","jsOnDisplay":"","jsOnTap":"","lastActivity":1607436537,"longId":13,"name":"Число рестартов модема","type":4}]

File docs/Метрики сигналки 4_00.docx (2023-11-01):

[{"iconOff":"ic_propeller_off","iconOn":"ic_propeller_on","offColor":-4144960,"onColor":-49088,"payloadOff":"0\u0026$","payloadOn":"1\u0026$","enableIntermediateState":true,"enablePub":true,"enteredIntermediateStateAt":0,"intermediateStateTimeout":100,"jsOnReceive":"","jsonPath":"","lastPayload":"0\u0026$","qos":0,"retained":false,"topic":"s/dvs","topicPub":"c/dvs","updateLastPayloadOnPub":false,"id":"a288d172-8150-4436-a131-9e5e308fcc2a","jsBlinkExpression":"","jsOnDisplay":"","jsOnTap":"","lastActivity":1606226790,"longId":1,"name":"Двигатель","type":2},{"items":[{"label":"10 мин","payload":"10\u0026$"},{"label":"15 мин","payload":"15\u0026$"},{"label":"20 мин","payload":"20\u0026$"},{"label":"25 мин","payload":"25\u0026$"},{"label":"30 мин","payload":"30\u0026$"},{"label":"45 мин","payload":"45\u0026$"},{"label":"1 час","payload":"59\u0026$"}],"mainTextSize":"LARGE","textColor":-16744193,"enableIntermediateState":true,"enablePub":true,"enteredIntermediateStateAt":0,"intermediateStateTimeout":9,"jsOnReceive":"","jsonPath":"","lastPayload":"OK","qos":0,"retained":false,"topic":"s/eti","topicPub":"c/Eti","updateLastPayloadOnPub":false,"id":"26fdbf2d-3bec-4b32-a112-7d05bd2a76c6","jsBlinkExpression":"","jsOnDisplay":"","jsOnTap":"","lastActivity":1606233720,"longId":7,"name":"Оставшееся время работы двигателя","type":4},{"iconOff":"ic_vpn_key","iconOn":"ic_vpn_key","offColor":-4144960,"onColor":-192,"payloadOff":"0","payloadOn":"1","enableIntermediateState":true,"enablePub":false,"enteredIntermediateStateAt":0,"intermediateStateTimeout":0,"jsOnReceive":"","jsonPath":"","lastPayload":"0","qos":0,"retained":false,"topic":"s/ign","topicPub":"","updateLastPayloadOnPub":true,"id":"27e100ec-81de-4f27-b02a-65508d72a6a4","jsBlinkExpression":"","jsOnDisplay":"","jsOnTap":"","lastActivity":1606226790,"longId":2,"name":"Зажигание","type":2},{"iconOff":"ic_lock_opened_outline","iconOn":"ic_lock_closed_outline","offColor":-16744193,"onColor":-12550144,"payloadOff":"0\u0026$","payloadOn":"1\u0026$","enableIntermediateState":true,"enablePub":false,"enteredIntermediateStateAt":0,"intermediateStateTimeout":8,"jsOnReceive":"","jsonPath":"","lastPayload":"0\u0026$","qos":0,"retained":false,"topic":"s/ohr","topicPub":"c/ohr","updateLastPayloadOnPub":false,"id":"466cddda-55b1-4d82-9c2a-32ae535b2f32","jsBlinkExpression":"","jsOnDisplay":"","jsOnTap":"","lastActivity":1606226790,"longId":3,"name":"Охрана","type":2},{"iconOff":"ic_autorenew","iconOn":"ic_autorenew","offColor":-64,"onColor":-64,"payloadOff":"0\u0026$","payloadOn":"1\u0026$","enableIntermediateState":true,"enablePub":true,"enteredIntermediateStateAt":0,"intermediateStateTimeout":0,"jsOnReceive":"","jsonPath":"","lastPayload":"1\u0026$","qos":0,"retained":false,"topic":"","topicPub":"c/ref","updateLastPayloadOnPub":true,"id":"9044399b-b43d-448e-b272-38356dc8eae2","jsBlinkExpression":"","jsOnDisplay":"","jsOnTap":"","lastActivity":1607450272,"longId":6,"name":"Обновить данные","type":2},{"iconOff":"ic_bell_off","iconOn":"ic_bell_on","offColor":-12550144,"onColor":-65536,"payloadOff":"0","payloadOn":"1","enableIntermediateState":true,"enablePub":false,"enteredIntermediateStateAt":0,"intermediateStateTimeout":0,"jsOnReceive":"","jsonPath":"","lastPayload":"0","qos":0,"retained":false,"topic":"s/tre","topicPub":"","updateLastPayloadOnPub":true,"id":"017649f5-6c0b-483e-96e4-a6472776e475","jsBlinkExpression":"","jsOnDisplay":"","jsOnTap":"","lastActivity":1606226790,"longId":4,"name":"Сирена, тревога","type":2}]

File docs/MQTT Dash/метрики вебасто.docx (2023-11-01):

[{"iconOff":"ic_check_box_unchecked","iconOn":"ic_check_box_checked","offColor":-1,"onColor":-12550144,"payloadOff":"0\u0026$","payloadOn":"1\u0026$","enableIntermediateState":true,"enablePub":true,"enteredIntermediateStateAt":0,"intermediateStateTimeout":10,"jsOnReceive":"","jsonPath":"","lastPayload":"0\u0026$","qos":0,"retained":false,"topic":"h/stat","topicPub":"h/ctrl","updateLastPayloadOnPub":false,"id":"5ffcabe0-f5f1-41d1-85ba-6b6ed51516ba","jsBlinkExpression":"","jsOnDisplay":"","jsOnTap":"","lastActivity":1573829676,"longId":1,"name":"Управление котлом ","type":2},{"iconOff":"ic_fire_01","iconOn":"ic_fire_01","offColor":-1,"onColor":-65536,"payloadOff":"0","payloadOn":"1","enableIntermediateState":true,"enablePub":false,"enteredIntermediateStateAt":0,"intermediateStateTimeout":0,"jsOnReceive":"","jsonPath":"","lastPayload":"0","qos":0,"retained":false,"topic":"h/flame","topicPub":"","updateLastPayloadOnPub":true,"id":"d93aae84-ebef-428a-8ddb-fb6a38319c15","jsBlinkExpression":"","jsOnDisplay":"","jsOnTap":"","lastActivity":1573829676,"longId":5,"name":"Состояние пламени","type":2},{"mainTextSize":"LARGE","postfix":"","prefix":"","textColor":-16744193,"enableIntermediateState":true,"enablePub":false,"enteredIntermediateStateAt":0,"intermediateStateTimeout":0,"jsOnReceive":"","jsonPath":"","lastPayload":"выкл","qos":1,"retained":false,"topic":"h/remtime","topicPub":"","updateLastPayloadOnPub":false,"id":"33324200-a8e6-49d6-a2f0-64db72375ba8","jsBlinkExpression":"","jsOnDisplay":"","jsOnTap":"","lastActivity":1573829676,"longId":4,"name":"Оставшееся время работы котла, мин","type":1},{"mainTextSize":"LARGE","postfix":"°","prefix":"","textColor":-16384,"enableIntermediateState":true,"enablePub":false,"enteredIntermediateStateAt":0,"intermediateStateTimeout":0,"jsOnReceive":"","jsonPath":"","lastPayload":"-101","qos":0,"retained":false,"topic":"h/temp/dvs","topicPub":"","updateLastPayloadOnPub":true,"id":"8d0ba876-9a4f-4045-8af4-db131043ecf8","jsBlinkExpression":"","jsOnDisplay":"","jsOnTap":"","lastActivity":1573829676,"longId":2,"name":"Температура двигателя","type":1},{"mainTextSize":"LARGE","postfix":"°","prefix":"","textColor":-16384,"enableIntermediateState":true,"enablePub":false,"enteredIntermediateStateAt":0,"intermediateStateTimeout":0,"jsOnReceive":"","jsonPath":"","lastPayload":"96","qos":0,"retained":false,"topic":"h/temp/heat","topicPub":"","updateLastPayloadOnPub":true,"id":"14197aca-5048-4d40-a2e2-b1222087e847","jsBlinkExpression":"","jsOnDisplay":"","jsOnTap":"","lastActivity":1573829676,"longId":6,"name":"Температура котла","type":1},{"items":[{"label":"15 мин","payload":"15\u0026$"},{"label":"20 мин","payload":"20\u0026$"},{"label":"30 мин","payload":"30\u0026$"},{"label":"45 мин","payload":"45\u0026$"},{"label":"1 час","payload":"59\u0026$"}],"mainTextSize":"LARGE","textColor":-16129,"enableIntermediateState":true,"enablePub":true,"enteredIntermediateStateAt":0,"intermediateStateTimeout":10,"jsOnReceive":"","jsonPath":"","lastPayload":"30","qos":0,"retained":false,"topic":"h/time/stat","topicPub":"h/time/ctrl","updateLastPayloadOnPub":false,"id":"117d0c7d-2b4c-4216-babc-e29fd5d2102a","jsBlinkExpression":"","jsOnDisplay":"","jsOnTap":"","lastActivity":1573829675,"longId":10,"name":"Установить время цикла, мин","type":4},{"mainTextSize":"LARGE","postfix":"°","prefix":"","textColor":-16384,"enableIntermediateState":true,"enablePub":false,"enteredIntermediateStateAt":0,"intermediateStateTimeout":0,"jsOnReceive":"","jsonPath":"","lastPayload":"-101","qos":0,"retained":false,"topic":"h/temp/ul","topicPub":"","updateLastPayloadOnPub":true,"id":"9c4dc9bd-db9e-48d7-964b-1f9bf64ef219","jsBlinkExpression":"","jsOnDisplay":"","jsOnTap":"","lastActivity":1573829676,"longId":7,"name":"Температура улицы","type":1},{"mainTextSize":"LARGE","postfix":"°","prefix":"","textColor":-16384,"enableIntermediateState":true,"enablePub":false,"enteredIntermediateStateAt":0,"intermediateStateTimeout":0,"jsOnReceive":"","jsonPath":"","lastPayload":"-101","qos":0,"retained":false,"topic":"h/temp/sal","topicPub":"","updateLastPayloadOnPub":true,"id":"12508932-d062-47f6-8c63-3ea8f457a758","jsBlinkExpression":"","jsOnDisplay":"","jsOnTap":"","lastActivity":1573829676,"longId":8,"name":"Температура салона","type":1},{"mainTextSize":"LARGE","postfix":"","prefix":"","textColor":-16384,"enableIntermediateState":true,"enablePub":false,"enteredIntermediateStateAt":0,"intermediateStateTimeout":0,"jsOnReceive":"","jsonPath":"","lastPayload":"-101","qos":0,"retained":false,"topic":"h/temp/vyh","topicPub":"","updateLastPayloadOnPub":true,"id":"d197b180-9a70-4b91-9526-038072024458","jsBlinkExpression":"","jsOnDisplay":"","jsOnTap":"","lastActivity":1573829676,"longId":16,"name":"Температура выхлопа","type":1},{"iconOff":"ic_loop_black","iconOn":"ic_loop_black","offColor":-4128896,"onColor":-4128896,"payloadOff":"0\u0026$","payloadOn":"1\u0026$","enableIntermediateState":false,"enablePub":true,"enteredIntermediateStateAt":1573829674,"intermediateStateTimeout":0,"jsOnReceive":"","jsonPath":"","qos":0,"retained":false,"topic":"","topicPub":"h/refr","updateLastPayloadOnPub":false,"id":"e217b0fb-4ba4-4a3a-addb-37312fcc9c61","jsBlinkExpression":"","jsOnDisplay":"","jsOnTap":"","lastActivity":0,"longId":11,"name":"Обновить данные","type":2},{"mainTextSize":"LARGE","postfix":"","prefix":"","textColor":-16744193,"enableIntermediateState":true,"enablePub":false,"enteredIntermediateStateAt":0,"intermediateStateTimeout":0,"jsOnReceive":"","jsonPath":"","lastPayload":"17.80","qos":0,"retained":false,"topic":"h/napr","topicPub":"","updateLastPayloadOnPub":true,"id":"3fbac020-95f7-4643-84e8-4c4936737699","jsBlinkExpression":"","jsOnDisplay":"","jsOnTap":"","lastActivity":1573829676,"longId":12,"name":"Напряжение бортовой сети, В","type":1},{"mainTextSize":"LARGE","postfix":"","prefix":"","textColor":-4194240,"enableIntermediateState":true,"enablePub":false,"enteredIntermediateStateAt":0,"intermediateStateTimeout":0,"jsOnReceive":"","jsonPath":"","lastPayload":"48","qos":0,"retained":false,"topic":"h/power","topicPub":"","updateLastPayloadOnPub":true,"id":"929719e8-0115-4c89-b3c0-44b0004446cc","jsBlinkExpression":"","jsOnDisplay":"","jsOnTap":"","lastActivity":1573829676,"longId":14,"name":"Мощность горения, %","type":1},{"items":[{"label":"сброс","payload":"0\u0026$"}],"mainTextSize":"LARGE","textColor":-16727809,"enableIntermediateState":true,"enablePub":true,"enteredIntermediateStateAt":0,"intermediateStateTimeout":8,"jsOnReceive":"","jsonPath":"","lastPayload":"0","qos":0,"retained":false,"topic":"h/resets","topicPub":"h/resresets","updateLastPayloadOnPub":false,"id":"1368a101-7da0-448f-864b-2f401f1e270d","jsBlinkExpression":"","jsOnDisplay":"","jsOnTap":"","lastActivity":1573829695,"longId":13,"name":"Число рестартов модема","type":4},{"mainTextSize":"LARGE","postfix":"","prefix":"","textColor":-192,"enableIntermediateState":true,"enablePub":false,"enteredIntermediateStateAt":0,"intermediateStateTimeout":0,"jsOnReceive":"","jsonPath":"","lastPayload":"2","qos":0,"retained":false,"topic":"h/dtcs","topicPub":"","updateLastPayloadOnPub":true,"id":"3ba386e0-ded5-402d-be29-7e04dee2d12e","jsBlinkExpression":"","jsOnDisplay":"","jsOnTap":"","lastActivity":1573829676,"longId":15,"name":"Количество ошибок котла","type":1}]

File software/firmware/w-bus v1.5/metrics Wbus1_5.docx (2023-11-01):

[{"iconOff":"ic_power_settings_new","iconOn":"ic_power_settings_new","offColor":-1,"onColor":-12550144,"payloadOff":"0\u0026$","payloadOn":"1\u0026$","enableIntermediateState":true,"enablePub":true,"enteredIntermediateStateAt":0,"intermediateStateTimeout":8,"jsOnReceive":"","jsonPath":"","lastPayload":"0\u0026$","qos":0,"retained":false,"topic":"s/hea","topicPub":"c/hea","updateLastPayloadOnPub":false,"id":"5ffcabe0-f5f1-41d1-85ba-6b6ed51516ba","jsBlinkExpression":"","jsOnDisplay":"","jsOnTap":"","lastActivity":1612296512,"longId":1,"name":"Управление котлом ","type":2},{"items":[{"label":"15 мин","payload":"15\u0026$"},{"label":"20 мин","payload":"20\u0026$"},{"label":"30 мин","payload":"30\u0026$"},{"label":"45 мин","payload":"45\u0026$"},{"label":"1 час","payload":"59\u0026$"}],"mainTextSize":"LARGE","textColor":-16129,"enableIntermediateState":true,"enablePub":true,"enteredIntermediateStateAt":0,"intermediateStateTimeout":10,"jsOnReceive":"","jsonPath":"","lastPayload":"30","qos":0,"retained":false,"topic":"s/tim","topicPub":"c/tim","updateLastPayloadOnPub":false,"id":"117d0c7d-2b4c-4216-babc-e29fd5d2102a","jsBlinkExpression":"","jsOnDisplay":"","jsOnTap":"","lastActivity":1612296512,"longId":10,"name":"Установить время цикла, мин","type":4},{"mainTextSize":"LARGE","postfix":"","prefix":"","textColor":-16744193,"enableIntermediateState":true,"enablePub":false,"enteredIntermediateStateAt":0,"intermediateStateTimeout":0,"jsOnReceive":"","jsonPath":"","lastPayload":"выкл","qos":1,"retained":false,"topic":"s/rti","topicPub":"","updateLastPayloadOnPub":false,"id":"33324200-a8e6-49d6-a2f0-64db72375ba8","jsBlinkExpression":"","jsOnDisplay":"","jsOnTap":"","lastActivity":1612296512,"longId":4,"name":"Оставшееся время работы котла, мин","type":1},{"mainTextSize":"LARGE","postfix":"°","prefix":"","textColor":-16384,"enableIntermediateState":true,"enablePub":false,"enteredIntermediateStateAt":0,"intermediateStateTimeout":0,"jsOnReceive":"","jsonPath":"","lastPayload":"-101","qos":0,"retained":false,"topic":"s/t/u","topicPub":"","updateLastPayloadOnPub":true,"id":"9c4dc9bd-db9e-48d7-964b-1f9bf64ef219","jsBlinkExpression":"","jsOnDisplay":"","jsOnTap":"","lastActivity":1612296512,"longId":7,"name":"Температура улицы","type":1},{"mainTextSize":"LARGE","postfix":"°","prefix":"","textColor":-16384,"enableIntermediateState":true,"enablePub":false,"enteredIntermediateStateAt":0,"intermediateStateTimeout":0,"jsOnReceive":"","jsonPath":"","lastPayload":"-101","qos":0,"retained":false,"topic":"s/t/s","topicPub":"","updateLastPayloadOnPub":true,"id":"12508932-d062-47f6-8c63-3ea8f457a758","jsBlinkExpression":"","jsOnDisplay":"","jsOnTap":"","lastActivity":1612296512,"longId":8,"name":"Температура салона","type":1},{"mainTextSize":"LARGE","postfix":"°","prefix":"","textColor":-16384,"enableIntermediateState":true,"enablePub":false,"enteredIntermediateStateAt":0,"intermediateStateTimeout":0,"jsOnReceive":"","jsonPath":"","lastPayload":"-101","qos":0,"retained":false,"topic":"s/t/d","topicPub":"","updateLastPayloadOnPub":true,"id":"8d0ba876-9a4f-4045-8af4-db131043ecf8","jsBlinkExpression":"","jsOnDisplay":"","jsOnTap":"","lastActivity":1612296512,"longId":2,"name":"Температура двигателя","type":1},{"mainTextSize":"LARGE","postfix":"°","prefix":"","textColor":-16384,"enableIntermediateState":true,"enablePub":false,"enteredIntermediateStateAt":0,"intermediateStateTimeout":0,"jsOnReceive":"","jsonPath":"","lastPayload":"wait","qos":0,"retained":false,"topic":"s/t/h","topicPub":"","updateLastPayloadOnPub":true,"id":"14197aca-5048-4d40-a2e2-b1222087e847","jsBlinkExpression":"","jsOnDisplay":"","jsOnTap":"","lastActivity":1612296512,"longId":6,"name":"Температура котла","type":1},{"mainTextSize":"LARGE","postfix":"","prefix":"","textColor":-4128960,"enableIntermediateState":true,"enablePub":false,"enteredIntermediateStateAt":0,"intermediateStateTimeout":0,"jsOnReceive":"","jsonPath":"","lastPayload":"wait","qos":0,"retained":false,"topic":"u","topicPub":"","updateLastPayloadOnPub":true,"id":"3fbac020-95f7-4643-84e8-4c4936737699","jsBlinkExpression":"","jsOnDisplay":"","jsOnTap":"","lastActivity":1612296512,"longId":12,"name":"Напряжение бортовой сети, В","type":1},{"mainTextSize":"LARGE","postfix":"","prefix":"","textColor":-4194240,"enableIntermediateState":true,"enablePub":false,"enteredIntermediateStateAt":0,"intermediateStateTimeout":0,"jsOnReceive":"","jsonPath":"","lastPayload":"wait","qos":0,"retained":false,"topic":"s/pow","topicPub":"","updateLastPayloadOnPub":true,"id":"929719e8-0115-4c89-b3c0-44b0004446cc","jsBlinkExpression":"","jsOnDisplay":"","jsOnTap":"","lastActivity":1612296512,"longId":14,"name":"Мощность горения, %","type":1},{"iconOff":"ic_fan_01","iconOn":"ic_fan_01","offColor":-1,"onColor":-4128960,"payloadOff":"0","payloadOn":"1","enableIntermediateState":true,"enablePub":false,"enteredIntermediateStateAt":0,"intermediateStateTimeout":0,"jsOnReceive":"","jsonPath":"","lastPayload":"1","qos":0,"retained":false,"topic":"s/pom","topicPub":"","updateLastPayloadOnPub":true,"id":"3f756738-4692-4910-b74a-8f75b479c226","jsBlinkExpression":"","jsOnDisplay":"","jsOnTap":"","lastActivity":1612296512,"longId":20,"name":"Водяная помпа","type":2},{"iconOff":"ic_fire_01","iconOn":"ic_fire_01","offColor":-1,"onColor":-65536,"payloadOff":"0","payloadOn":"1","enableIntermediateState":true,"enablePub":false,"enteredIntermediateStateAt":0,"intermediateStateTimeout":0,"jsOnReceive":"","jsonPath":"","lastPayload":"0","qos":0,"retained":false,"topic":"s/fla","topicPub":"","updateLastPayloadOnPub":true,"id":"d93aae84-ebef-428a-8ddb-fb6a38319c15","jsBlinkExpression":"","jsOnDisplay":"","jsOnTap":"","lastActivity":1612296512,"longId":5,"name":"Состояние пламени","type":2},{"items":[{"label":"Удалить ошибки","payload":"1\u0026$"}],"mainTextSize":"LARGE","textColor":-65344,"enableIntermediateState":true,"enablePub":true,"enteredIntermediateStateAt":0,"intermediateStateTimeout":10,"jsOnReceive":"","jsonPath":"","lastPayload":"wait","qos":0,"retained":false,"topic":"s/dtc","topicPub":"c/ecl","updateLastPayloadOnPub":false,"id":"ab04578b-641b-43af-89a1-53f980310998","jsBlinkExpression":"","jsOnDisplay":"","jsOnTap":"","lastActivity":1612296512,"longId":19,"name":"Количество ошибок /удалить","type":4},{"iconOff":"ic_water_tap_03","iconOn":"ic_water_tap_03","offColor":-1,"onColor":-16384,"payloadOff":"0","payloadOn":"1","enableIntermediateState":true,"enablePub":false,"enteredIntermediateStateAt":0,"intermediateStateTimeout":0,"jsOnReceive":"","jsonPath":"","lastPayload":"1","qos":0,"retained":false,"topic":"s/fue","topicPub":"","updateLastPayloadOnPub":true,"id":"faf16c6c-3add-42c4-8623-e01e6842ca7a","jsBlinkExpression":"","jsOnDisplay":"","jsOnTap":"","lastActivity":1612296512,"longId":21,"name":"Топливный насос","type":2},{"iconOff":"ic_fan_05","iconOn":"ic_fan_05","offColor":-1,"onColor":-16744193,"payloadOff":"0","payloadOn":"1","enableIntermediateState":true,"enablePub":false,"enteredIntermediateStateAt":0,"intermediateStateTimeout":0,"jsOnReceive":"","jsonPath":"","lastPayload":"1","qos":0,"retained":false,"topic":"s/aif","topicPub":"","updateLastPayloadOnPub":true,"id":"e0491e36-5cc9-47d2-9651-7ccbe6716b6f","jsBlinkExpression":"","jsOnDisplay":"","jsOnTap":"","lastActivity":1612296512,"longId":22,"name":"Нагнетатель воздуха","type":2},{"iconOff":"ic_ignition","iconOn":"ic_ignition","offColor":-1,"onColor":-65472,"payloadOff":"0","payloadOn":"1","enableIntermediateState":true,"enablePub":false,"enteredIntermediateStateAt":0,"intermediateStateTimeout":0,"jsOnReceive":"","jsonPath":"","lastPayload":"1","qos":0,"retained":false,"topic":"s/plg","topicPub":"","updateLastPayloadOnPub":true,"id":"ca29bab9-6cba-466e-b91a-8dc469316a43","jsBlinkExpression":"","jsOnDisplay":"","jsOnTap":"","lastActivity":1612296512,"longId":23,"name":"Свеча накала","type":2},{"iconOff":"ic_loop_black","iconOn":"ic_loop_black","offColor":-4128896,"onColor":-4128896,"payloadOff":"0\u0026$","payloadOn":"1\u0026$","enableIntermediateState":false,"enablePub":true,"enteredIntermediateStateAt":1612296510,"intermediateStateTimeout":0,"jsOnReceive":"","jsonPath":"","qos":0,"retained":false,"topic":"","topicPub":"c/ref","updateLastPayloadOnPub":false,"id":"e217b0fb-4ba4-4a3a-addb-37312fcc9c61","jsBlinkExpression":"","jsOnDisplay":"","jsOnTap":"","lastActivity":0,"longId":11,"name":"Обновить данные","type":2},{"mainTextSize":"LARGE","postfix":"","prefix":"","textColor":-16760640,"enableIntermediateState":true,"enablePub":false,"enteredIntermediateStateAt":0,"intermediateStateTimeout":0,"jsOnReceive":"","jsonPath":"","lastPayload":"20","qos":0,"retained":false,"topic":"s/lev","topicPub":"","updateLastPayloadOnPub":true,"id":"ba3a84d1-e4ca-4aff-9690-7e0f2bab59e0","jsBlinkExpression":"","jsOnDisplay":"","jsOnTap":"","lastActivity":1612296512,"longId":17,"name":"Уровень сигнала GSM","type":1},{"items":[{"label":"сброс","payload":"0\u0026$"}],"mainTextSize":"LARGE","textColor":-16727809,"enableIntermediateState":true,"enablePub":true,"enteredIntermediateStateAt":0,"intermediateStateTimeout":8,"jsOnReceive":"","jsonPath":"","lastPayload":"0","qos":0,"retained":false,"topic":"s/res","topicPub":"c/Res","updateLastPayloadOnPub":false,"id":"1368a101-7da0-448f-864b-2f401f1e270d","jsBlinkExpression":"","jsOnDisplay":"","jsOnTap":"","lastActivity":1612296512,"longId":13,"name":"Число рестартов модема","type":4}]

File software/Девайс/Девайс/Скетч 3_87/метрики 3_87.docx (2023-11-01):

[{"iconOff":"ic_power_settings_new","iconOn":"ic_power_settings_new","offColor":-1,"onColor":-12550144,"payloadOff":"0\u0026$","payloadOn":"1\u0026$","enableIntermediateState":true,"enablePub":true,"enteredIntermediateStateAt":0,"intermediateStateTimeout":8,"jsOnReceive":"","jsonPath":"","lastPayload":"1\u0026$","qos":0,"retained":false,"topic":"r/heat","topicPub":"d/heat","updateLastPayloadOnPub":false,"id":"5ffcabe0-f5f1-41d1-85ba-6b6ed51516ba","jsBlinkExpression":"","jsOnDisplay":"","jsOnTap":"","lastActivity":1574353099,"longId":1,"name":"Управление котлом ","type":2},{"iconOff":"ic_fire_01","iconOn":"ic_fire_01","offColor":-1,"onColor":-65536,"payloadOff":"0","payloadOn":"1","enableIntermediateState":true,"enablePub":false,"enteredIntermediateStateAt":0,"intermediateStateTimeout":0,"jsOnReceive":"","jsonPath":"","lastPayload":"0","qos":0,"retained":false,"topic":"r/flame","topicPub":"","updateLastPayloadOnPub":true,"id":"d93aae84-ebef-428a-8ddb-fb6a38319c15","jsBlinkExpression":"","jsOnDisplay":"","jsOnTap":"","lastActivity":1574353099,"longId":5,"name":"Состояние пламени","type":2},{"iconOff":"ic_loop_black","iconOn":"ic_loop_black","offColor":-4128896,"onColor":-4128896,"payloadOff":"0\u0026$","payloadOn":"1\u0026$","enableIntermediateState":false,"enablePub":true,"enteredIntermediateStateAt":1574352641,"intermediateStateTimeout":0,"jsOnReceive":"","jsonPath":"","qos":0,"retained":false,"topic":"","topicPub":"d/refr","updateLastPayloadOnPub":false,"id":"e217b0fb-4ba4-4a3a-addb-37312fcc9c61","jsBlinkExpression":"","jsOnDisplay":"","jsOnTap":"","lastActivity":0,"longId":11,"name":"Обновить данные","type":2},{"mainTextSize":"LARGE","postfix":"","prefix":"","textColor":-16744193,"enableIntermediateState":true,"enablePub":false,"enteredIntermediateStateAt":0,"intermediateStateTimeout":0,"jsOnReceive":"","jsonPath":"","lastPayload":"19","qos":1,"retained":false,"topic":"r/remtime","topicPub":"","updateLastPayloadOnPub":false,"id":"33324200-a8e6-49d6-a2f0-64db72375ba8","jsBlinkExpression":"","jsOnDisplay":"","jsOnTap":"","lastActivity":1574353099,"longId":4,"name":"Оставшееся время работы котла, мин","type":1},{"items":[{"label":"15 мин","payload":"15\u0026$"},{"label":"20 мин","payload":"20\u0026$"},{"label":"30 мин","payload":"30\u0026$"},{"label":"45 мин","payload":"45\u0026$"},{"label":"1 час","payload":"59\u0026$"}],"mainTextSize":"LARGE","textColor":-16129,"enableIntermediateState":true,"enablePub":true,"enteredIntermediateStateAt":0,"intermediateStateTimeout":10,"jsOnReceive":"","jsonPath":"","lastPayload":"20","qos":0,"retained":false,"topic":"r/time","topicPub":"d/time","updateLastPayloadOnPub":false,"id":"117d0c7d-2b4c-4216-babc-e29fd5d2102a","jsBlinkExpression":"","jsOnDisplay":"","jsOnTap":"","lastActivity":1574353099,"longId":10,"name":"Установить время цикла, мин","type":4},{"iconOff":"ic_lock_opened_outline","iconOn":"ic_lock_closed_outline","offColor":-49088,"onColor":-12550144,"payloadOff":"0\u0026$","payloadOn":"1\u0026$","enableIntermediateState":true,"enablePub":true,"enteredIntermediateStateAt":1574353019,"intermediateStateTimeout":0,"jsOnReceive":"","jsonPath":"","lastPayload":"0\u0026$","qos":0,"retained":false,"topic":"","topicPub":"d/lock","updateLastPayloadOnPub":true,"id":"69e70c7d-0dc2-4ba9-b17a-688b08757308","jsBlinkExpression":"","jsOnDisplay":"","jsOnTap":"","lastActivity":1574353019,"longId":18,"name":"Замки","type":2},{"mainTextSize":"LARGE","postfix":"°","prefix":"","textColor":-16384,"enableIntermediateState":true,"enablePub":false,"enteredIntermediateStateAt":0,"intermediateStateTimeout":0,"jsOnReceive":"","jsonPath":"","lastPayload":"-50","qos":0,"retained":false,"topic":"r/temp/heat","topicPub":"","updateLastPayloadOnPub":true,"id":"14197aca-5048-4d40-a2e2-b1222087e847","jsBlinkExpression":"","jsOnDisplay":"","jsOnTap":"","lastActivity":1574353099,"longId":6,"name":"Температура котла","type":1},{"mainTextSize":"LARGE","postfix":"°","prefix":"","textColor":-16384,"enableIntermediateState":true,"enablePub":false,"enteredIntermediateStateAt":0,"intermediateStateTimeout":0,"jsOnReceive":"","jsonPath":"","lastPayload":"-101","qos":0,"retained":false,"topic":"r/temp/ul","topicPub":"","updateLastPayloadOnPub":true,"id":"9c4dc9bd-db9e-48d7-964b-1f9bf64ef219","jsBlinkExpression":"","jsOnDisplay":"","jsOnTap":"","lastActivity":1574353099,"longId":7,"name":"Температура улицы","type":1},{"mainTextSize":"LARGE","postfix":"°","prefix":"","textColor":-16384,"enableIntermediateState":true,"enablePub":false,"enteredIntermediateStateAt":0,"intermediateStateTimeout":0,"jsOnReceive":"","jsonPath":"","lastPayload":"-101","qos":0,"retained":false,"topic":"r/temp/sal","topicPub":"","updateLastPayloadOnPub":true,"id":"12508932-d062-47f6-8c63-3ea8f457a758","jsBlinkExpression":"","jsOnDisplay":"","jsOnTap":"","lastActivity":1574353099,"longId":8,"name":"Температура салона","type":1},{"mainTextSize":"LARGE","postfix":"°","prefix":"","textColor":-16384,"enableIntermediateState":true,"enablePub":false,"enteredIntermediateStateAt":0,"intermediateStateTimeout":0,"jsOnReceive":"","jsonPath":"","lastPayload":"-101","qos":0,"retained":false,"topic":"r/temp/dvs","topicPub":"","updateLastPayloadOnPub":true,"id":"8d0ba876-9a4f-4045-8af4-db131043ecf8","jsBlinkExpression":"","jsOnDisplay":"","jsOnTap":"","lastActivity":1574353099,"longId":2,"name":"Температура двигателя","type":1},{"mainTextSize":"LARGE","postfix":"","prefix":"","textColor":-4128960,"enableIntermediateState":true,"enablePub":false,"enteredIntermediateStateAt":0,"intermediateStateTimeout":0,"jsOnReceive":"","jsonPath":"","lastPayload":"0.00","qos":0,"retained":false,"topic":"r/napr","topicPub":"","updateLastPayloadOnPub":true,"id":"3fbac020-95f7-4643-84e8-4c4936737699","jsBlinkExpression":"","jsOnDisplay":"","jsOnTap":"","lastActivity":1574353099,"longId":12,"name":"Напряжение бортовой сети, В","type":1},{"mainTextSize":"LARGE","postfix":"","prefix":"","textColor":-4194240,"enableIntermediateState":true,"enablePub":false,"enteredIntermediateStateAt":0,"intermediateStateTimeout":0,"jsOnReceive":"","jsonPath":"","lastPayload":"0","qos":0,"retained":false,"topic":"r/power","topicPub":"","updateLastPayloadOnPub":true,"id":"929719e8-0115-4c89-b3c0-44b0004446cc","jsBlinkExpression":"","jsOnDisplay":"","jsOnTap":"","lastActivity":1574353099,"longId":14,"name":"Мощность горения, %","type":1},{"mainTextSize":"LARGE","postfix":"","prefix":"","textColor":-65344,"enableIntermediateState":true,"enablePub":false,"enteredIntermediateStateAt":0,"intermediateStateTimeout":0,"jsOnReceive":"","jsonPath":"","lastPayload":"0","qos":0,"retained":false,"topic":"r/dtc","topicPub":"","updateLastPayloadOnPub":true,"id":"3ba386e0-ded5-402d-be29-7e04dee2d12e","jsBlinkExpression":"","jsOnDisplay":"","jsOnTap":"","lastActivity":1574353099,"longId":15,"name":"Количество ошибок котла","type":1},{"mainTextSize":"LARGE","postfix":"","prefix":"","textColor":-49088,"enableIntermediateState":true,"enablePub":false,"enteredIntermediateStateAt":0,"intermediateStateTimeout":0,"jsOnReceive":"","jsonPath":"","lastPayload":"0","qos":0,"retained":false,"topic":"r/flout","topicPub":"","updateLastPayloadOnPub":true,"id":"ba3a84d1-e4ca-4aff-9690-7e0f2bab59e0","jsBlinkExpression":"","jsOnDisplay":"","jsOnTap":"","lastActivity":1574353099,"longId":17,"name":"Счетчик срывов пламени","type":1},{"items":[{"label":"сброс","payload":"0\u0026$"}],"mainTextSize":"LARGE","textColor":-16727809,"enableIntermediateState":true,"enablePub":true,"enteredIntermediateStateAt":0,"intermediateStateTimeout":8,"jsOnReceive":"","jsonPath":"","lastPayload":"3","qos":0,"retained":false,"topic":"r/resets","topicPub":"d/resres","updateLastPayloadOnPub":false,"id":"1368a101-7da0-448f-864b-2f401f1e270d","jsBlinkExpression":"","jsOnDisplay":"","jsOnTap":"","lastActivity":1574353099,"longId":13,"name":"Число рестартов модема","type":4}]

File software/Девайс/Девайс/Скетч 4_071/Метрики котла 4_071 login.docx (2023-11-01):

[{"iconOff":"ic_power_settings_new","iconOn":"ic_power_settings_new","offColor":-1,"onColor":-12550144,"payloadOff":"0\u0026$","payloadOn":"1\u0026$","enableIntermediateState":true,"enablePub":true,"enteredIntermediateStateAt":0,"intermediateStateTimeout":8,"jsOnReceive":"","jsonPath":"","lastPayload":"0\u0026$","qos":0,"retained":false,"topic":"login/s/hea","topicPub":"login/c/hea","updateLastPayloadOnPub":false,"id":"5ffcabe0-f5f1-41d1-85ba-6b6ed51516ba","jsBlinkExpression":"","jsOnDisplay":"","jsOnTap":"","lastActivity":1607790566,"longId":1,"name":"Управление котлом ","type":2},{"iconOff":"ic_fire_01","iconOn":"ic_fire_01","offColor":-1,"onColor":-65536,"payloadOff":"0","payloadOn":"1","enableIntermediateState":true,"enablePub":false,"enteredIntermediateStateAt":0,"intermediateStateTimeout":0,"jsOnReceive":"","jsonPath":"","lastPayload":"0","qos":0,"retained":false,"topic":"login/s/fla","topicPub":"","updateLastPayloadOnPub":true,"id":"d93aae84-ebef-428a-8ddb-fb6a38319c15","jsBlinkExpression":"","jsOnDisplay":"","jsOnTap":"","lastActivity":1607790566,"longId":5,"name":"Состояние пламени","type":2},{"mainTextSize":"LARGE","postfix":"°","prefix":"","textColor":-16384,"enableIntermediateState":true,"enablePub":false,"enteredIntermediateStateAt":0,"intermediateStateTimeout":0,"jsOnReceive":"","jsonPath":"","lastPayload":"-101","qos":0,"retained":false,"topic":"login/s/t/v","topicPub":"","updateLastPayloadOnPub":true,"id":"c4476183-0093-4d20-8800-250a604ab522","jsBlinkExpression":"","jsOnDisplay":"","jsOnTap":"","lastActivity":1607790566,"longId":18,"name":"Температура выхлопа","type":1},{"mainTextSize":"LARGE","postfix":"","prefix":"","textColor":-16744193,"enableIntermediateState":true,"enablePub":false,"enteredIntermediateStateAt":0,"intermediateStateTimeout":0,"jsOnReceive":"","jsonPath":"","lastPayload":"выкл","qos":1,"retained":false,"topic":"login/s/rti","topicPub":"","updateLastPayloadOnPub":false,"id":"33324200-a8e6-49d6-a2f0-64db72375ba8","jsBlinkExpression":"","jsOnDisplay":"","jsOnTap":"","lastActivity":1607790566,"longId":4,"name":"Оставшееся время работы котла, мин","type":1},{"items":[{"label":"15 мин","payload":"15\u0026$"},{"label":"20 мин","payload":"20\u0026$"},{"label":"30 мин","payload":"30\u0026$"},{"label":"45 мин","payload":"45\u0026$"},{"label":"1 час","payload":"59\u0026$"}],"mainTextSize":"LARGE","textColor":-16129,"enableIntermediateState":true,"enablePub":true,"enteredIntermediateStateAt":0,"intermediateStateTimeout":10,"jsOnReceive":"","jsonPath":"","lastPayload":"15","qos":0,"retained":false,"topic":"login/s/tim","topicPub":"login/c/tim","updateLastPayloadOnPub":false,"id":"117d0c7d-2b4c-4216-babc-e29fd5d2102a","jsBlinkExpression":"","jsOnDisplay":"","jsOnTap":"","lastActivity":1607790566,"longId":10,"name":"Установить время цикла, мин","type":4},{"mainTextSize":"LARGE","postfix":"°","prefix":"","textColor":-16384,"enableIntermediateState":true,"enablePub":false,"enteredIntermediateStateAt":0,"intermediateStateTimeout":0,"jsOnReceive":"","jsonPath":"","lastPayload":"fail","qos":0,"retained":false,"topic":"login/s/t/h","topicPub":"","updateLastPayloadOnPub":true,"id":"14197aca-5048-4d40-a2e2-b1222087e847","jsBlinkExpression":"","jsOnDisplay":"","jsOnTap":"","lastActivity":1607790577,"longId":6,"name":"Температура котла","type":1},{"mainTextSize":"LARGE","postfix":"°","prefix":"","textColor":-16384,"enableIntermediateState":true,"enablePub":false,"enteredIntermediateStateAt":0,"intermediateStateTimeout":0,"jsOnReceive":"","jsonPath":"","lastPayload":"-101","qos":0,"retained":false,"topic":"login/s/t/u","topicPub":"","updateLastPayloadOnPub":true,"id":"9c4dc9bd-db9e-48d7-964b-1f9bf64ef219","jsBlinkExpression":"","jsOnDisplay":"","jsOnTap":"","lastActivity":1607790566,"longId":7,"name":"Температура улицы","type":1},{"mainTextSize":"LARGE","postfix":"°","prefix":"","textColor":-16384,"enableIntermediateState":true,"enablePub":false,"enteredIntermediateStateAt":0,"intermediateStateTimeout":0,"jsOnReceive":"","jsonPath":"","lastPayload":"-101","qos":0,"retained":false,"topic":"login/s/t/s","topicPub":"","updateLastPayloadOnPub":true,"id":"12508932-d062-47f6-8c63-3ea8f457a758","jsBlinkExpression":"","jsOnDisplay":"","jsOnTap":"","lastActivity":1607790566,"longId":8,"name":"Температура салона","type":1},{"mainTextSize":"LARGE","postfix":"°","prefix":"","textColor":-16384,"enableIntermediateState":true,"enablePub":false,"enteredIntermediateStateAt":0,"intermediateStateTimeout":0,"jsOnReceive":"","jsonPath":"","lastPayload":"-101","qos":0,"retained":false,"topic":"login/s/t/d","topicPub":"","updateLastPayloadOnPub":true,"id":"8d0ba876-9a4f-4045-8af4-db131043ecf8","jsBlinkExpression":"","jsOnDisplay":"","jsOnTap":"","lastActivity":1607790566,"longId":2,"name":"Температура двигателя","type":1},{"mainTextSize":"LARGE","postfix":"","prefix":"","textColor":-4128960,"enableIntermediateState":true,"enablePub":false,"enteredIntermediateStateAt":0,"intermediateStateTimeout":0,"jsOnReceive":"","jsonPath":"","lastPayload":"fail","qos":0,"retained":false,"topic":"login/u","topicPub":"","updateLastPayloadOnPub":true,"id":"3fbac020-95f7-4643-84e8-4c4936737699","jsBlinkExpression":"","jsOnDisplay":"","jsOnTap":"","lastActivity":1607790577,"longId":12,"name":"Напряжение бортовой сети, В","type":1},{"mainTextSize":"LARGE","postfix":"","prefix":"","textColor":-4194240,"enableIntermediateState":true,"enablePub":false,"enteredIntermediateStateAt":0,"intermediateStateTimeout":0,"jsOnReceive":"","jsonPath":"","lastPayload":"fail","qos":0,"retained":false,"topic":"login/s/pow","topicPub":"","updateLastPayloadOnPub":true,"id":"929719e8-0115-4c89-b3c0-44b0004446cc","jsBlinkExpression":"","jsOnDisplay":"","jsOnTap":"","lastActivity":1607790577,"longId":14,"name":"Мощность горения, %","type":1},{"items":[{"label":"Удалить ошибки","payload":"1\u0026$"}],"mainTextSize":"LARGE","textColor":-65344,"enableIntermediateState":true,"enablePub":true,"enteredIntermediateStateAt":0,"intermediateStateTimeout":10,"jsOnReceive":"","jsonPath":"","lastPayload":"fail","qos":0,"retained":false,"topic":"login/s/dtc","topicPub":"login/c/ecl","updateLastPayloadOnPub":false,"id":"ab04578b-641b-43af-89a1-53f980310998","jsBlinkExpression":"","jsOnDisplay":"","jsOnTap":"","lastActivity":1607790577,"longId":19,"name":"Количество ошибок /удалить","type":4},{"iconOff":"ic_loop_black","iconOn":"ic_loop_black","offColor":-4128896,"onColor":-4128896,"payloadOff":"0\u0026$","payloadOn":"1\u0026$","enableIntermediateState":false,"enablePub":true,"enteredIntermediateStateAt":0,"intermediateStateTimeout":0,"jsOnReceive":"","jsonPath":"","qos":0,"retained":false,"topic":"","topicPub":"login/c/ref","updateLastPayloadOnPub":false,"id":"e217b0fb-4ba4-4a3a-addb-37312fcc9c61","jsBlinkExpression":"","jsOnDisplay":"","jsOnTap":"","lastActivity":0,"longId":11,"name":"Обновить данные","type":2},{"mainTextSize":"LARGE","postfix":"","prefix":"","textColor":-16760640,"enableIntermediateState":true,"enablePub":false,"enteredIntermediateStateAt":0,"intermediateStateTimeout":0,"jsOnReceive":"","jsonPath":"","lastPayload":"28","qos":0,"retained":false,"topic":"login/s/lev","topicPub":"","updateLastPayloadOnPub":true,"id":"ba3a84d1-e4ca-4aff-9690-7e0f2bab59e0","jsBlinkExpression":"","jsOnDisplay":"","jsOnTap":"","lastActivity":1607790566,"longId":17,"name":"Уровень сигнала GSM","type":1},{"items":[{"label":"сброс","payload":"0\u0026$"}],"mainTextSize":"LARGE","textColor":-16727809,"enableIntermediateState":true,"enablePub":true,"enteredIntermediateStateAt":0,"intermediateStateTimeout":8,"jsOnReceive":"","jsonPath":"","lastPayload":"1","qos":0,"retained":false,"topic":"login/s/res","topicPub":"login/c/Res","updateLastPayloadOnPub":false,"id":"1368a101-7da0-448f-864b-2f401f1e270d","jsBlinkExpression":"","jsOnDisplay":"","jsOnTap":"","lastActivity":1607790566,"longId":13,"name":"Число рестартов модема","type":4}]

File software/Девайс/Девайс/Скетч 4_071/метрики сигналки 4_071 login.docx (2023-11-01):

[{"iconOff":"ic_propeller_off","iconOn":"ic_propeller_on","offColor":-4144960,"onColor":-49088,"payloadOff":"0\u0026$","payloadOn":"1\u0026$","enableIntermediateState":true,"enablePub":true,"enteredIntermediateStateAt":0,"intermediateStateTimeout":100,"jsOnReceive":"","jsonPath":"","lastPayload":"0\u0026$","qos":0,"retained":false,"topic":"login/s/dvs","topicPub":"login/c/dvs","updateLastPayloadOnPub":false,"id":"a288d172-8150-4436-a131-9e5e308fcc2a","jsBlinkExpression":"","jsOnDisplay":"","jsOnTap":"","lastActivity":1607767922,"longId":1,"name":"Двигатель","type":2},{"items":[{"label":"10 мин","payload":"10\u0026$"},{"label":"15 мин","payload":"15\u0026$"},{"label":"20 мин","payload":"20\u0026$"},{"label":"25 мин","payload":"25\u0026$"},{"label":"30 мин","payload":"30\u0026$"},{"label":"45 мин","payload":"45\u0026$"},{"label":"1 час","payload":"59\u0026$"}],"mainTextSize":"LARGE","textColor":-16744193,"enableIntermediateState":true,"enablePub":true,"enteredIntermediateStateAt":0,"intermediateStateTimeout":9,"jsOnReceive":"","jsonPath":"","lastPayload":"выкл","qos":0,"retained":false,"topic":"login/s/eti","topicPub":"login/c/Eti","updateLastPayloadOnPub":false,"id":"26fdbf2d-3bec-4b32-a112-7d05bd2a76c6","jsBlinkExpression":"","jsOnDisplay":"","jsOnTap":"","lastActivity":1607767922,"longId":7,"name":"Оставшееся время работы двигателя","type":4},{"iconOff":"ic_vpn_key","iconOn":"ic_vpn_key","offColor":-4144960,"onColor":-192,"payloadOff":"0","payloadOn":"1","enableIntermediateState":true,"enablePub":false,"enteredIntermediateStateAt":0,"intermediateStateTimeout":0,"jsOnReceive":"","jsonPath":"","lastPayload":"0","qos":0,"retained":false,"topic":"login/s/ign","topicPub":"","updateLastPayloadOnPub":true,"id":"27e100ec-81de-4f27-b02a-65508d72a6a4","jsBlinkExpression":"","jsOnDisplay":"","jsOnTap":"","lastActivity":1607767922,"longId":2,"name":"Зажигание","type":2},{"iconOff":"ic_lock_opened_outline","iconOn":"ic_lock_closed_outline","offColor":-16744193,"onColor":-12550144,"payloadOff":"0\u0026$","payloadOn":"1\u0026$","enableIntermediateState":true,"enablePub":false,"enteredIntermediateStateAt":0,"intermediateStateTimeout":8,"jsOnReceive":"","jsonPath":"","lastPayload":"0\u0026$","qos":0,"retained":false,"topic":"login/s/ohr","topicPub":"login/c/ohr","updateLastPayloadOnPub":false,"id":"466cddda-55b1-4d82-9c2a-32ae535b2f32","jsBlinkExpression":"","jsOnDisplay":"","jsOnTap":"","lastActivity":1607767922,"longId":3,"name":"Охрана","type":2},{"iconOff":"ic_autorenew","iconOn":"ic_autorenew","offColor":-64,"onColor":-64,"payloadOff":"0\u0026$","payloadOn":"1\u0026$","enableIntermediateState":true,"enablePub":true,"enteredIntermediateStateAt":0,"intermediateStateTimeout":0,"jsOnReceive":"","jsonPath":"","lastPayload":"1\u0026$","qos":0,"retained":false,"topic":"","topicPub":"login/c/ref","updateLastPayloadOnPub":true,"id":"9044399b-b43d-448e-b272-38356dc8eae2","jsBlinkExpression":"","jsOnDisplay":"","jsOnTap":"","lastActivity":1607767919,"longId":6,"name":"Обновить данные","type":2},{"iconOff":"ic_bell_off","iconOn":"ic_bell_on","offColor":-12550144,"onColor":-65536,"payloadOff":"0","payloadOn":"1","enableIntermediateState":true,"enablePub":false,"enteredIntermediateStateAt":0,"intermediateStateTimeout":0,"jsOnReceive":"","jsonPath":"","lastPayload":"0","qos":0,"retained":false,"topic":"login/s/tre","topicPub":"","updateLastPayloadOnPub":true,"id":"017649f5-6c0b-483e-96e4-a6472776e475","jsBlinkExpression":"","jsOnDisplay":"","jsOnTap":"","lastActivity":1607767922,"longId":4,"name":"Сирена, тревога","type":2}]

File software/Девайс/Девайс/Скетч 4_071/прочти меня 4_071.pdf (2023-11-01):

Скетч v4.07 поддерживает MQTT брокер как Cloudmqtt.com так и Clusterfly.ru .

### Вверху скетча выбираем тип котла, наличие подключения сигналки и необходимость работы по

MQTT. Тип котла также дополнительно необходимо выбирать в скетче еепром или по смс.

Регистрации на clusterfly.ru как таковой не нужно. Можно зайти через любой аккаунт типа yandex, google, mail и т.д. Работаем через сервер [SRV.1] . Заходим в "профиль", Там смотрим адрес сервера, номер порта tcp , пользователь (username), и пароль. Забиваем эти данные вверху скетча.

На этом брокере все топики должны начинаться с username аккаунта брокера. Поэтому универсальные метрики не подойдут и их нужно править: открываем в ворде метрики (лежат в этой папке). По умолчанию значение username там login . Ставим курсор в начало. Нажимаем ctrl+H (найти и заменить) во всплывшем окне в поле "найти" пишем login . Ниже в поле "Заменить на:" пишем ВАШ! username и нажимаем кнопку "Заменить все". Сохраняем ворд файл на всякий. На брокере чуть ниже кнопки "профиль", нажимаем Web-client. Вбиваем пароль и нажимаем "подключиться". В соответствующем поле пишем название топика: met

Открываем на смартфоне MQTT Dash и создаем панель управления, вбиваем имя польз, пароль, сервер и порт. Заходим. Нажимаем вверху "две стрелочки". В поле "топик"
пишем: username/met (Естественно вместо username ВАШе имя пользователя) и нажимаем "ПОДПИСАТЬСЯ И ЖДАТЬ МЕТРИКИ".

Копируем весь исправленный текст метрик (в ворде) в буфер обмена. На брокере в поле "сообщение" вставляем этот текст (ctrl+v) и нажимаем отправить.

Всё, на смартфоне метрики должны получиться. Если мигают, перезайти в приложение.

Если по прежнему используете брокер cloudmqtt метрики готовим таким же способом.

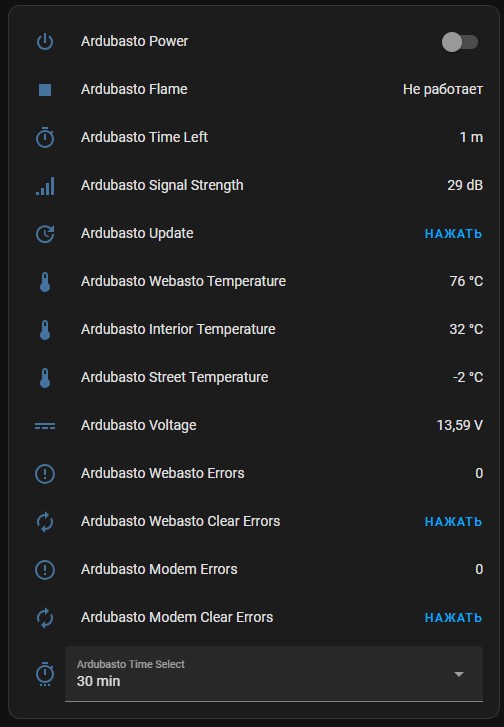
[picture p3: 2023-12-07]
docs/images/HA_screenshot.jpg

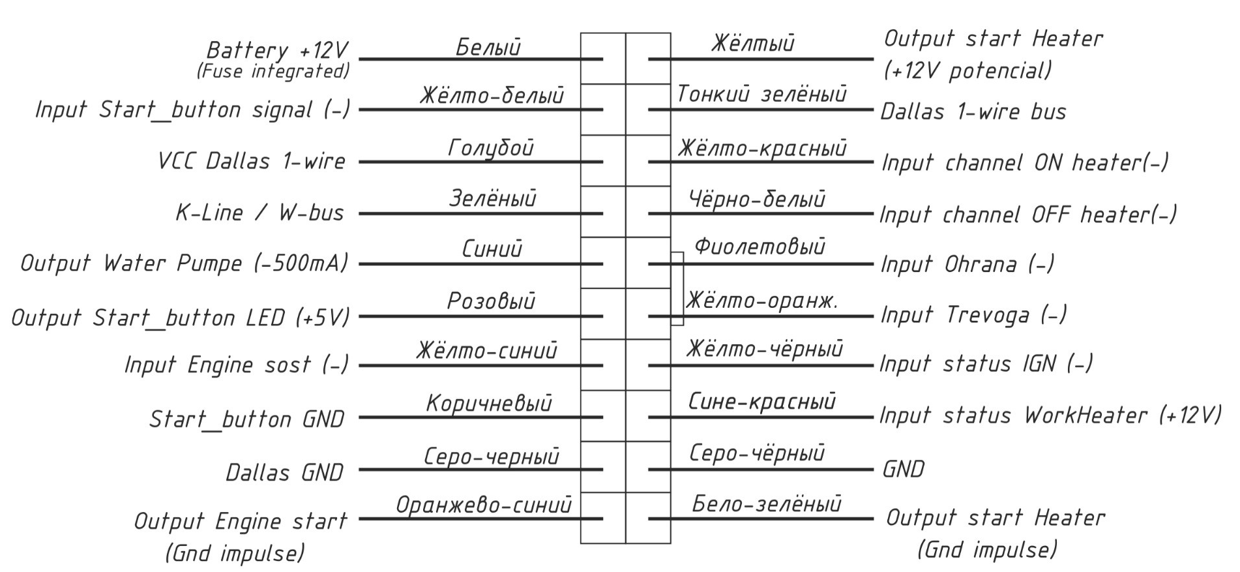
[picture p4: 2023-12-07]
docs/images/Connector.jpg

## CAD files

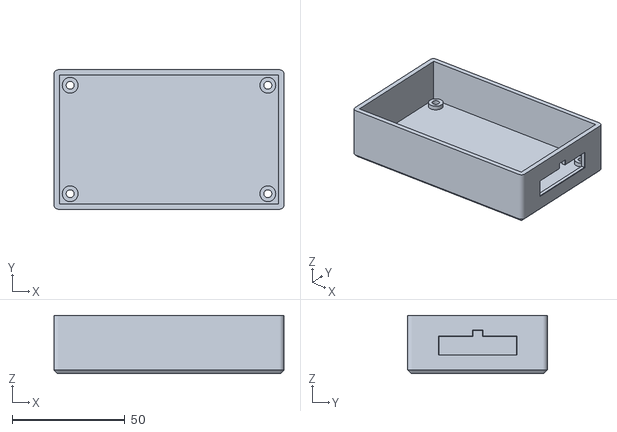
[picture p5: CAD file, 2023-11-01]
hardware/housing/bottom.STL
101.8 x 61.8 x 25.7

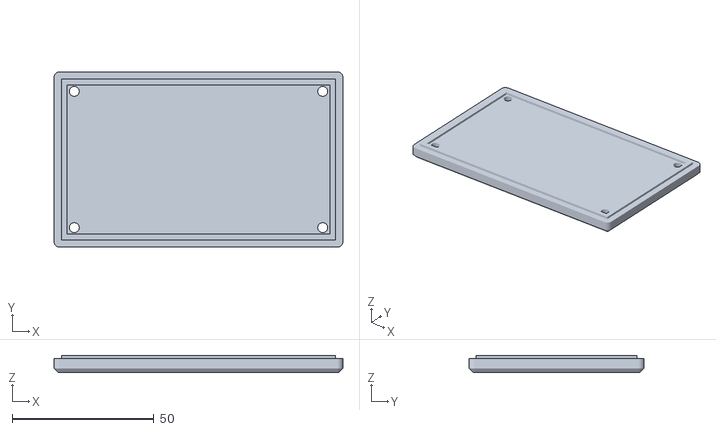
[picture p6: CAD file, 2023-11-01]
hardware/housing/top.STL
101.8 x 61.8 x 6.00

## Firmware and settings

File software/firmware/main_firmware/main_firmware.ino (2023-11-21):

const char ver[] = "v4.54";    // 

//#define WBUS_heaters    // тут раскомментируем одну из строчек 
#define TTE_C_heaters   // с нужным типом котла

//#define Signalka        // раскомментировать , если к девайсу подключена сигнализация

bool mqtt = 1;          // работа по MQTT (интернету) 1 - включено, 0 - выключено. 

//#define DEBUG_MODEM   // раскомментировать , если нужно отладить модем (k-line при этом отключать)


//---------------------------Настройки MQTT-----------------------------------------------------------------------------

const char ACCESSPOINT[]= "\"internet.mts.by\"";          // точка доступа оператора связи симкарты
const char MQTTUSER[]    =  "username";                  // имя пользователя (логин)  (смотрим в аккаунте MQTT)
const char MQTTPASSWORD[] = "securepassword";                // пароль                    (смотрим в аккаунте MQTT)
const char SERVERNAME_PORT[] = "\"mqtt.mosquitto.com\", \"1883\"";  // адрес и порт (смотрим в аккаунте MQTT)
                                                                    // на cloudmqtt  смотрим просто "Port" (без SSL)
                                                                   
//----------------------------------название ячеек еепром----------------------------------------------------------------
#include <EEPROM.h>
enum Cells 
{
ResetNumber_cell,     //0
TimeWebasto_cell,     //1
ProtocolSTART_cell,   //2
StartByte_cell,       //3
ProtocolSTATUS_cell,  //4
HeaterBUS_cell,       //5
WBUS_VER_cell,        //6
delta_cell,           //7
CentrLock_cell,       //8
EngineTime_cell,      //9
PumpeTime_cell,       //10
sizeNumber_cell,      //11
TelNumber1_cell =20,  //20
TelNumber2_cell =40,  //40
DallasAddr_cell =60   //60
};

//------------------- распиновка ног ардуино (плата весий 8.8-8.93)--------------------------------------------------------

#define OutWebasto_12V      2  // это +12В выход потенциала вкл/выкл вебасто (напрямую к котлу без таймера). 
#define Dallas_pin          3  // пин шины OneWire для датчиков даллас
#define DopOn_pin           4  // сюда доп канал от сигналки на включение вебасто
#define DopOff_pin          5  // сюда доп канал от сигналки на выключение вебасто
#define Ohrana_pin          6  // Сюда состояние охраны сигналки
#define Trevoga_pin         7  // Сюда состояние тревоги
#define IGN_pin             8  // Сюда состояние зажигания
#define Sost_pin            9 // Сюда состояние вебасто (+12В когда работает)
#define ResetGSM           12  // пин ресета GSM подключен к реле, разрывающее питание модуля. 
#define PUMPE              13  // пин управления помпой
#define Eng_pin            14  // (А0) Сюда состояние работы ДВС
#define StatusWebastoLED   15  // (А1) пин LED  индикация включенности котла
#define StartButtonpin     16  // (А2) пин тактовой кнопки вкл/выкл котла 
#define DTR                17  // пин (А3), управляющий энергосберегающим режимом GSM модуля
#define StartEng           18  // (A4) это импульсный минусовой выход вкл/выкл ДВС. подключать на вход событий сиги.
#define OutWebasto_GndImp  19  // пин (A5) это импульсный минусовой выход вкл/выкл вебасто (к впайке к кнопке таймера). 
#define SLDATA_TX          20  // этот пин цеплять на цифровую шину старлайн SL-DATA (на RX - левый пин если смотреть на разъем сиги. Центр там GND . Правый это Tx)
#define Voltmeter_pin      A7  // пин, которым измеряем напряжение питания
const bool RelayON =        1; // логика управления реле ресета GSM, в данном случае включается высоким уровнем на пине
#define GSM_RX             10  // пин софт RX Arduino для соединения с TX модуля SIM800
#define GSM_TX             11  // пин софт TX Arduino для соединения с RX модуля SIM800

enum BuTTons {StartButton, DopOnButton, DopOffButton, EngineButton, IGNButton, OhranaButton, TrevogaButton, SostButton};

//-----------------------------для шины SL_DATA сигнализаций старлайн-----------------------------------------------------

#define BIT_DURATION  190  //время одного бита в микросекундах для шины SL_DATA
const uint16_t SL_START_ENG  = 8670;
const uint16_t SL_STOP_ENG   = 8415;
const uint16_t SL_OHRANA_ON  = 4590;
const uint16_t SL_OHRANA_OFF = 4335;

//------------------------------------для GSM модуля----------------------------------------------------------------------

#include <SoftwareSerial.h>
      SoftwareSerial SIM800 (GSM_RX, GSM_TX);//Rx, Tx   //UART для соединения с GSM модулем


const char PROTOCOLIUS[] =  "MQIsdp";                 // протокол MQTT
const char MQTTNAME[]    =  "b";                      // инстанс MQTT
#define TIMEBROKER 20   // таймаут бездействия клиента брокера, минут. Если превысить - с сервера выкинет 

bool smszapusk = 0;
char currStr[60];   
char TelNumber[][16] = {"", "", "", ""};
byte isStringMessage = 0; 
byte KTOreport = 1;           // флаг кто запросил отчет о запуске котла или ДВС
byte KTOzapros = 0;           // флаг кто запросил баланс или запрос параметров 
byte ResetNumber = 0;         // количество ресетов GSM модуля для статистики (хранится в еепром)
byte SizeTelNumber = 12;      // количество символов в номере телефона

const uint16_t Refresh_interval_heaterON = 30000; // интервал обновления параметров по MQTT при включенном котле, миллисек    
uint32_t prev_refreshMQTT = 0;
uint32_t prevGSMnastr = 0;
uint32_t prevTestModem = 0;
const byte interval_doprosGSM = 1; // интервал проверки модема на активность, мин  
uint16_t delayATcommand = 5000;
byte fails = 0;
byte failresets = 0;

bool settingGSM = 1;
bool TimerMQTTreconnect = 0;       // таймер переподключения к брокеру если были 4 неудачных попытки
uint32_t prevModemReboot = 0; bool smsModemReboot_timer = 0; // таймер ребута модема по смс
byte signalLevelstatus = 3;        // состояние уровня gsm сети
byte last_signalLevelstatus = 3;   // прошлое состояние уровня gsm сети
byte signalLevel = 0;              // уровень сигнала gsm сети 

enum gsmstatus_  
{
  WaitGSM, echoOFF, EnergySave, Head, setText, setProgctrl, closeIncoming, newMessage, delSMS, // настройки для СМС
  setGPRS, setAccPoint, setGPRSconnect, setBrokerconnect, setAuthPack, setSubPack, checkLevel,  setPubPack  // настройки для MQTT
};

byte gsmstatus = WaitGSM;

char buffeR[16] = {0};   // буффер для работы функций вытаскивания строк из прогмем 
char buffVAR[10] = {0};  // буффер для работы функций конвертации переменных в char 

#define ENDSTR 1

const char Zapros []        PROGMEM = "Zapros"; 
const char Service_info []  PROGMEM = "Service-info"; 
const char Erase_DTC []     PROGMEM = "Erase DTC";
const char Zaprostel []     PROGMEM = "Zaprostel";
const char GSMResets_0[]    PROGMEM = "GSMResets";
const char Version[]        PROGMEM = "Version";
const char MQTT_reset[]     PROGMEM = "MQTT-reset";
const char MQTT_ON[]        PROGMEM = "MQTT-ON";
const char MQTT_OFF[]       PROGMEM = "MQTT-OFF";
const char Webasto_ON[]     PROGMEM = "Heater-ON";
const char Webasto_OFF[]    PROGMEM = "Heater-OFF";
const char Engine_ON[]      PROGMEM = "Engine-ON";
const char Engine_OFF[]     PROGMEM = "Engine-OFF";
const char Impulse[]        PROGMEM = "Impulse";
const char Startbus[]       PROGMEM = "Startbus";
const char Potencial[]      PROGMEM = "Potencial";
const char DallasAddr[]     PROGMEM = "DallasAddr";
const char Status[]         PROGMEM = "Status";
const char HeaterBusType[]  PROGMEM = "HeaterBusType";
const char ADDr[]           PROGMEM = "address";
const char Delta[]          PROGMEM = "Delta";
const char Min[]            PROGMEM = "min";
const char StartBytE[]      PROGMEM = "StartByte";
const char ResetNumbers[]   PROGMEM = "ResetNumbers";
const char WriteNumber2[]   PROGMEM = "WriteNumber2";
const char Balance[]        PROGMEM = "Balance";
const char WriteNumber1[]   PROGMEM = "WriteNumber1";
const char cmt[]            PROGMEM = "+CMT: \"";
const char cusd[]           PROGMEM = "+CUSD: 0,";
const char csq[]            PROGMEM = "+CSQ:";
const char Closed[]         PROGMEM = "CLOSED";
const char okey[]           PROGMEM = "OK";
const char Connect[]        PROGMEM = "CONNECT";
const char SendOk[]         PROGMEM = "SEND OK";
const char Space[]          PROGMEM = " ";
const char ErroR[]          PROGMEM = "ERROR";
const char Bus[]            PROGMEM = "BUS";
const char Wbus[]           PROGMEM = "W-BUS";
const char ttce[]           PROGMEM = "TTC_E";
const char hydronic[]       PROGMEM = "Hydronic";
const char analog[]         PROGMEM = "Analog";


const char WAIT[] PROGMEM = "wait";
const char FAIL[] PROGMEM = "fail";
const char VYKL[] PROGMEM = "выкл";

//---------------------------Топики MQTT--------------------------------------------------------------------------------
const char CTRL_HEAT_TOP[]    PROGMEM = "c/hea";
const char CTRL_TIME_TOP[]    PROGMEM = "c/tim";
const char CTRL_TIMEENG_TOP[] PROGMEM = "c/Eti";
const char CTRL_REFRESH_TOP[] PROGMEM = "c/ref";
const char CTRL_RESRES_TOP[]  PROGMEM = "c/Res";
const char CTRL_LOCK_TOP[]    PROGMEM = "c/loc";
const char CTRL_DVS_TOP[]     PROGMEM = "c/dvs";
const char CTRL_DTC_CL[]      PROGMEM = "c/ecl";
const char CTRL_OHR_TOP[]     PROGMEM = "c/ohr";

const char STAT_HEAT_TOP[]    PROGMEM = "s/hea";
const char STAT_TIME_TOP[]    PROGMEM = "s/tim";
const char STAT_RESETS_TOP[]  PROGMEM = "s/res";
const char STAT_FLAME_TOP[]   PROGMEM = "s/fla";
const char STAT_POWER_TOP[]   PROGMEM = "s/pow";
const char STAT_DTS_TOP[]     PROGMEM = "s/dtc";
const char STAT_LEVEL_TOP[]   PROGMEM = "s/lev";
const char STAT_NAPR_TOP[]    PROGMEM = "u";
const char STAT_REMTIME_TOP[] PROGMEM = "s/rti";
const char STAT_ENGTIME_TOP[] PROGMEM = "s/eti";
const char tHEAT_TOP[]        PROGMEM = "s/t/h";
const char tDVS_TOP[]         PROGMEM = "s/t/d";
const char tUL_TOP[]          PROGMEM = "s/t/u";
const char tSAL_TOP[]         PROGMEM = "s/t/s";
const char tVYH_TOP[]         PROGMEM = "s/t/v";
const char STAT_ENGINE_TOP[]  PROGMEM = "s/dvs";
const char STAT_IGN_TOP[]     PROGMEM = "s/ign";
const char STAT_OHR_TOP[]     PROGMEM = "s/ohr";
const char STAT_TREV_TOP[]    PROGMEM = "s/tre";
const char STAT_WPUMP_TOP[]   PROGMEM = "s/pom";
const char STAT_PLUG_TOP[]    PROGMEM = "s/plg";
const char STAT_FAN_TOP[]     PROGMEM = "s/aif";
const char STAT_FPUMP_TOP[]   PROGMEM = "s/fue";

const char SUBSCRIBE_TOP[]    PROGMEM = "/c/#";
//------------------------------------------------------------------------------------------------------------------


const char* const PGMtable[] PROGMEM = 
{
Zapros,
Service_info,
Erase_DTC,
Zaprostel,
GSMResets_0,
Version,
MQTT_reset,
MQTT_ON,
MQTT_OFF,
Webasto_ON,
Webasto_OFF,
Engine_ON,
Engine_OFF,
Impulse,
Startbus,
Potencial,
DallasAddr,
Status,
HeaterBusType,
ADDr,
Delta,
Min,
StartBytE,
ResetNumbers,
WriteNumber2,
Balance,
WriteNumber1,
cmt,
cusd,
csq,
Closed,
okey,
Connect,
SendOk,
Space,
ErroR,
Bus,
Wbus,
ttce,
hydronic,
analog,

WAIT,
FAIL,
VYKL,

CTRL_HEAT_TOP,
CTRL_TIME_TOP,
CTRL_TIMEENG_TOP,
CTRL_REFRESH_TOP,
CTRL_RESRES_TOP,
CTRL_LOCK_TOP,
CTRL_DVS_TOP,
CTRL_DTC_CL,
CTRL_OHR_TOP,

STAT_HEAT_TOP,
STAT_TIME_TOP,
STAT_RESETS_TOP,
STAT_FLAME_TOP,
STAT_POWER_TOP,
STAT_DTS_TOP,
STAT_LEVEL_TOP,
STAT_NAPR_TOP,
STAT_REMTIME_TOP,
STAT_ENGTIME_TOP,
tHEAT_TOP,
tDVS_TOP,
tUL_TOP,
tSAL_TOP,
tVYH_TOP,
STAT_ENGINE_TOP,
STAT_IGN_TOP,
STAT_OHR_TOP,
STAT_TREV_TOP,
STAT_WPUMP_TOP,
STAT_PLUG_TOP,
STAT_FAN_TOP,
STAT_FPUMP_TOP,

SUBSCRIBE_TOP

};

enum PGMtable_
{
_ZAPROS,
_SERVICE_INFO,
_ERASE_DTC,
_ZAPROSTEL,
_GSM_RESETS,
_VERSION,
_MQTT_RESET,
_MQTT_ON,
_MQTT_OFF,
_HEATER_ON,
_HEATER_OFF,
_ENGINE_ON,
_ENGINE_OFF,
_IMPULSE,
_STARTBUS,
_POTENCIAL,
_DALLASADDR,
_STATUS,
_HEATERBUSTYPE,
_ADDRESSA,
_DELTA,
_MIN,
_STARTBYTE,
_RESETNUMBERS,
_WRITENUMBER2,
_BALANCE,
_WRITENUMBER1,
_CMT,
_CUSD,
_CSQ,
_CLOSED,
_OK,
_CONNECT,
_SEND_OK,
_SPACE,
_ERROR,
_BUS,
_WBUS,
_TTCE,
_HYDRONIC,
_ANALOG,

_WAIT,
_FAIL,
_VYKL,

_CTRL_HEAT_TOP,
_CTRL_TIME_TOP,
_CTRL_TIMEENG_TOP,
_CTRL_REFRESH_TOP,
_CTRL_RESRES_TOP,
_CTRL_LOCK_TOP,
_CTRL_DVS_TOP,
_CTRL_DTC_CL,
_CTRL_OHR_TOP,

_STAT_HEAT_TOP,
_STAT_TIME_TOP,
_STAT_RESETS_TOP,
_STAT_FLAME_TOP,
_STAT_POWER_TOP,
_STAT_DTS_TOP,
_STAT_LEVEL_TOP,
_STAT_NAPR_TOP,
_STAT_REMTIME_TOP,
_STAT_ENGTIME_TOP,
_tHEAT_TOP,
_tDVS_TOP,
_tUL_TOP,
_tSAL_TOP,
_tVYH_TOP,
_STAT_ENGINE_TOP,
_STAT_IGN_TOP,
_STAT_OHR_TOP,
_STAT_TREV_TOP,
_STAT_WPUMP_TOP,
_STAT_PLUG_TOP,
_STAT_FAN_TOP,
_STAT_FPUMP_TOP,
_SUBSCRIBE_TOP
};


//------------------- для шины 1-wire и датчиков DS18B20---------------------------------------------------------------------

#include <OneWire.h>    // библиотека для DS18B20
OneWire ds(Dallas_pin); // датчики DS18B20 на нужный пин

enum TempC {VyhlopC, EngineC, UlicaC, SalonC, size_arrayTemp}; // перечисление нужных температур (в конце размер массива температур)

struct dallasSens 
{
  byte DSaddress[8];
  int Temper;
  char TempName[10];
}; 

dallasSens DS18B20[size_arrayTemp] = 
 {
    { {0x28, 0xFF, 0xB2, 0xB5, 0xC1, 0x17, 0x05, 0xD1}, -100, "Vyhlop" },
    { {0x28, 0xFF, 0xD3, 0xE2, 0xC1, 0x17, 0x04, 0x0D}, -100, "Engine" },
    { {0x28, 0xFF, 0xF8, 0xBC, 0xC1, 0x17, 0x04, 0x48}, -100, "Ulica"  },
    { {0x28, 0xFF, 0x3F, 0xB7, 0xC1, 0x17, 0x05, 0xF1}, -100, "Salon"  }
 };

byte delta = 50;  // разница температур выхлопа и улицы, выше которой считается, что пламя в котле есть (для протокола статусов по аналогу)
int8_t HeaterC = -50;

//---------------------------для организации взаимодействия с котлом по цифровой шине и различные таймеры----------------------------

#include <Button.h>
Button test;

#define K_LINE Serial      //UART для соединения с шиной котла
#define TX 1    

// команды для котлов с шиной W-BUS
byte StartByte = 0x20;
const byte HEATER_BEGIN[]         {0x51, 0x0A};
      byte HEATER_START[]         {StartByte, 0x3B};
      byte HEATER_PRESENCE[]      {0x44, StartByte, 0x00};
const byte HEATER_STOP[]          {0x10};
const byte HEATER_STATUS_VEVO[]   {0x50, 0x05};
const byte HEATER_STATUS_VEVO07[] {0x50, 0x07};
const byte HEATER_STATUS_EVO[]    {0x50, 0x30, 0x0A, 0x0C, 0x0E, 0x10, 0x12, 0x1E, 0x32, 0x6F};
const byte HEATER_DTC_REQUEST[]   {0x56, 0x01};
const byte HEATER_DTC_ERASE[]     {0x56, 0x03};

// команды для котлов ТТС/TTE с шиной К-line
const byte START_SESSION[]       {0x81};
const byte REQUEST_2A0101[]      {0x2A, 0x01, 0x01};
const byte REQUEST_2A0102[]      {0x2A, 0x01, 0x02};
const byte REQUEST_2A0105[]      {0x2A, 0x01, 0x05};
const byte REQUEST_DTC[]         {0xA1};
const byte CLEAR_DTC[]           {0x14};
const byte START_TTC[]           {0x31, 0x22, 0xFF};
const byte START_PRESENCE[]      {0x31, 0x22, 0x01};
const byte STOP_TTC[]            {0x31, 0x22, 0x00};


enum needAction_ {NO_ACTION, NEED_SMSZAPROS, NEED_SERVICEINFO, NEED_MQTTZAPROS, NEED_DTCCLEAR};// возможные действия, стоящие в очереди
byte needAction = NO_ACTION;                                                  // переменная действия, стоящего в очереди

enum ProtocolSTATUS_ {STATUSBUS=1, ANALOG};                 // возможные протоколы чтения статуса котла
enum ProtocolSTART_  {STARTBUS=1, IMPULSE, POTENCIAL};      // возможные протоколы запуска котла
enum HeaterBUSTYPE_         {TTC_E=1, WBUS, HYDRONIC};      // тип шины котла


byte  ProtocolSTATUS = STATUSBUS; 
byte  ProtocolSTART  = STARTBUS;
byte  HeaterBUSTYPE = WBUS;
byte  WBUS_VER = 0x40;   

bool noData  = 0;                               // флаг пришли ли данные от котла после запроса. 
byte w_bus_init = 0;                            //состояние инициализация шины w-bus (25мс LOW, 25мс HIGH для  ЭВО
                                                //                                            либо 300ms LOW, 50ms HIGH, 25ms LOW, 3025ms HIGH для TTC 

byte StartMessageRepeat = 0;                    //количество отправленных сообщений на старт котла
byte StopMessageRepeat =  4;                    //количество отправленных сообщений на остановку котла

byte  TimeWebasto = 30;                         //время работы котла, = 30мин

uint32_t currmillis = 0;                        // снимок системного времени
uint32_t Prev_PeriodW_BusMessage = 0;           //переменная для таймера периодической отправки сообщений состояния котла в шину W-Bus 
uint32_t Prev_PeriodW_BusStartStop = 0;         //переменная для таймера периодической отправки сообщений старта/стопа котла в шину W-Bus 
uint32_t prevdelSMS = 0;                        //переменная для таймера периодического удаления СМС 
uint32_t prevInitreset = 0;                     //переменная для таймера сброса инита шины
bool Initreset = 0;                             //переменная для таймера сброса инита шины
uint32_t timerInit = 0;                         //для таймера инита шины W-BUS

bool TimerVklData = 0;                             //
uint32_t timerVklData = 0;                         //



uint32_t prevNeedTimer = 0; bool NeedTimer = 0; //для таймера задержки функций SMSzapros() и ServiceINFO() на время обновления параметров по шине
bool waitingNextMes = 0;                        //для таймера задержки между сообщениями на шине 10400 TTC
                   
uint32_t prevReportEngine = 0; bool reportEngine = false;    //таймер задержки на отправку отчёта о запуске двигателя
uint32_t prevReport = 0;bool report = false;                 //таймер задержки на отправку отчёта о запуске котла
uint32_t last_Flame = 0;                                     //для таймера сброса флага пламени, если нет ответов от котла
uint32_t prevGND_impulse = 0; bool GND_impulse_timer = 0;    //для таймера создания импульса GND - для протокола запуска котла импульсом GND 

byte EngineTime = 1;

uint32_t prevPumpe=0; bool Pumpe_timer=0;                    //для таймера  - работы помпы после выключения котла
byte PumpeTime = 1;                                          //сек, время работы помпы после выключения котла
bool CentrLock = 0;
uint32_t prevWorkCycleHeater; bool WorkCycleHeater_timer=0;  //для таймера отсчёта цикла работы котла
uint32_t prevWorkCycleEngine = 0;                            //для таймера отсчёта цикла работы двигателя
bool EngWorkTimer = 0 ; 
byte TimeEngine = 30;                                        //время работы двигателя


//---------------------------------Основные переменные--------------------------------------------------------------------------------  

bool webasto = 0;             // флаг команды на работу Webasto. 0 - котел выключен, 1 - котел включен
bool startWebasto_OK = 0;     // флаг успешного запуска котла

float  Vpit = 0.0;            // Измеряемое напряжение бортсети 
bool engine =0;               // флаг работает ли ДВС или нет
bool ignition=0;              // флаг включено ли зажигание или нет
bool ohrana=0;                // флаг включена ли охрана или нет
bool trevoga=0;               // флаг включена ли тревога или нет
int PowerHeater= 0;           // мощность работы котла
bool waterpump = 0;           // флаг работы циркуляционного насоса
bool plug      = 0;           // флаг работы штифта накаливания
bool airfan    = 0;           // флаг работы нагнетателя воздуха
bool fuelpump  = 0;           // флаг работы топливного насоса
bool blowerfan = 0;           // флаг работы вентилятора печки автомобиля
byte flameout  = 0;           // количество срывов пламени
byte DTC[13] ={0};            // коды неисправностей котла
byte countDTC = 0; 
//---------------------------СТАРТОВЫЙ ЦИКЛ--------------------------------------------------------------------------------------------



void setup() 
{
delay (4500);
test.NO(); 
test.pullUp();
test.duration_bounce       (  50);
test.duration_click_Db     ( 250);
test.duration_inactivity_Up(5000);
test.duration_inactivity_Dn(1000);
test.duration_press        ( 500);
//enum BuTTons {StartButton,    DopOnButton, DopOffButton, EngineButton, IGNButton, OhranaButton, TrevogaButton, SostButton};
test.button    (StartButtonpin, DopOn_pin,   DopOff_pin,   Eng_pin,      IGN_pin,   Ohrana_pin,   Trevoga_pin, Sost_pin);
 
pinMode (OutWebasto_12V,     OUTPUT);  digitalWrite (OutWebasto_12V,      LOW);
pinMode (SLDATA_TX ,         OUTPUT);  digitalWrite (SLDATA_TX ,         HIGH);
pinMode (StartEng,           OUTPUT);  digitalWrite (StartEng,            LOW);
pinMode (PUMPE,              OUTPUT);  digitalWrite (PUMPE,               LOW);
pinMode (StatusWebastoLED,   OUTPUT);  digitalWrite (StatusWebastoLED,    LOW);
pinMode (OutWebasto_GndImp,  OUTPUT);  digitalWrite (OutWebasto_GndImp,   LOW);
pinMode (DTR,                OUTPUT);  digitalWrite (DTR,                 LOW );  // делаем низкий для вывода GSM из "спячки"
pinMode (ResetGSM,           OUTPUT);  digitalWrite (ResetGSM,        !RelayON);  // реле ресет на данный момент делаем "неактивно"
  
  SIM800.begin(9600);           // сериал соединение для gsm модуля
   

SizeTelNumber =  EEPROM.read(sizeNumber_cell);
if (SizeTelNumber>25)while(1);
TimeWebasto =    EEPROM.read(TimeWebasto_cell);
ProtocolSTART  = EEPROM.read(ProtocolSTART_cell);
ProtocolSTATUS = EEPROM.read(ProtocolSTATUS_cell);
ResetNumber =    EEPROM.read(ResetNumber_cell);
StartByte =      EEPROM.read(StartByte_cell);
HEATER_START[0] = StartByte;
HEATER_PRESENCE[1] = StartByte;
HeaterBUSTYPE =  EEPROM.read(HeaterBUS_cell);
WBUS_VER      =  EEPROM.read(WBUS_VER_cell);
delta  =         EEPROM.read(delta_cell);
CentrLock  =     EEPROM.read(CentrLock_cell);
EngineTime     = EEPROM.read (EngineTime_cell);
PumpeTime      = EEPROM.read (PumpeTime_cell);
for (int i=0; i<SizeTelNumber; i++) 
    {
      char bu[2] = "0";
      strcat (TelNumber[0],bu);
      strcat (TelNumber[3],bu);
      
      bu[0] = (char)EEPROM.read (i+TelNumber1_cell);
      strcat (TelNumber[1],bu);
      bu[0] = (char)EEPROM.read (i+TelNumber2_cell);
      strcat (TelNumber[2],bu);
    }
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
void loop() 
{
  currmillis = millis();
  test.read();
  Check_responseModem ();
  readModem();   
 Heater_BUS();
 timers_and_buttons ();
 izmereniya();
}

//-----------------------------------------------------------конец луп-------------------------------------------------------------

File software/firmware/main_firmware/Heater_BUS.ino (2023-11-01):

void Heater_BUS ()
{
  static byte requiredmessage =  1;   // что отправляем в данный момент поддержание старта, запрос параметров или запрос ошибок
  static byte header = 0;             // состояние заголовка 
  static byte message_size = 0;       // размер тела принимаемого сообщения, кол-во байт
  static byte j = 2;                  // инкремент
  static byte n = 2;
  const byte bufsize = 140;           // размер буфера принятого сообщения
  static byte buf [bufsize] = {0};    // буфер принятого сообщения
  static byte checksum = 0;           // контрольная сумма входящего сообщения
  static uint32_t prevRESETheader=0;  // таймер сброса заголовка если в момент приёма сообщения данные оборвались
  static bool RESETheader_timer = 0;  // таймер сброса заголовка если в момент приёма сообщения данные оборвались

#ifdef WBUS_heaters
if      (HeaterBUSTYPE == WBUS){
if (webasto) 
{
    if (StartMessageRepeat<4 && (currmillis-Prev_PeriodW_BusStartStop>800) && w_bus_init >= 9){
  sendMessage (HEATER_START, sizeof(HEATER_START)); 
  StartMessageRepeat++; 
  Prev_PeriodW_BusStartStop = currmillis;
  
    }
  if (StartMessageRepeat>=4)
  { 
      if (currmillis-Prev_PeriodW_BusMessage>4000)  
       {
         if (requiredmessage==1) sendMessage (HEATER_PRESENCE, sizeof(HEATER_PRESENCE));  
    else if (requiredmessage==2) {if (WBUS_VER >= 0x40) sendMessage (HEATER_STATUS_EVO,  sizeof(HEATER_STATUS_EVO));
                                  if (WBUS_VER >= 0x30 && WBUS_VER < 0x40)sendMessage (HEATER_STATUS_VEVO, sizeof(HEATER_STATUS_VEVO));}
    else if (requiredmessage==3) sendMessage (HEATER_DTC_REQUEST, sizeof(HEATER_DTC_REQUEST));  
requiredmessage++; if (requiredmessage > 3) requiredmessage = 1;
StopMessageRepeat = 0;
    
    Prev_PeriodW_BusMessage = currmillis;
       }
  }
}

else if (StopMessageRepeat<4 && (currmillis-Prev_PeriodW_BusStartStop>800))
{
  sendMessage (HEATER_STOP, sizeof(HEATER_STOP));
  StopMessageRepeat++; 
  StartMessageRepeat = 0;
  Prev_PeriodW_BusStartStop = currmillis;
}


     if (w_bus_init==1) {K_LINE.end(); pinMode (TX, OUTPUT); digitalWrite(TX, 0); timerInit = millis(); w_bus_init++;}
else if (w_bus_init==2 && millis() - timerInit>24) {timerInit = currmillis; digitalWrite(TX, 1); w_bus_init++; }
else if (w_bus_init==3 && millis() - timerInit>24) {K_LINE.begin (2400,SERIAL_8E1 ); w_bus_init=9; 
                                                    if (needAction>0) sendMessage (HEATER_BEGIN, sizeof(HEATER_BEGIN));}


if (K_LINE.available()){
    

 // первый старт байт
 if (header == 0){buf[0]=K_LINE.read();  
         if (buf[0]==0x4F || buf[0]==0x44){header = 1; RESETheader_timer=1; prevRESETheader = currmillis; }
         else {header = 0; RESETheader_timer=0;}
         }                  

 // длина сообщения
 else if (header == 1 ){buf[1]=K_LINE.read(); message_size = buf[1]; if (message_size > bufsize) message_size = bufsize;  header = 4;j=2;n=2;checksum = 0;} 

 // пишем тело сообщения 
 else if (header == 4 && j< message_size+n) {
 buf[j] = K_LINE.read();
 
 if (j<message_size+n-1) checksum^= buf[j]; // подсчёт КС
 
 if (j==message_size+n-1) header = 5; 
  j++;} 

 } // end of K_LINE.available()

 // сообщение приняли, действуем
 if (header == 5) {  
   
for(byte i = 0; i<n; i++) checksum^=buf[i]; // прибавляем к контрольной сумме старт байты

 // если контрольная сумма верна: 
if ( checksum == buf[message_size+n-1]) {

prevInitreset = currmillis;  // нулим таймер сброса инита
noData = 0;
   if (buf[0]==0x44 && buf[2]==0xC4 && buf[3]==0x00) {w_bus_init = 1; delay (500); K_LINE.flush();}  // если получили от котла сбой инита, делаем переинит 
   if (buf[2]==0xD1 && buf[3]==0x0A)  {w_bus_init = 10; if (WBUS_VER != buf[4]) WBUS_VER = buf[4], EEPROM.write(WBUS_VER_cell, WBUS_VER);}  //если получили ответ на старт коммуникации 
   if ((buf[2]^0x80)==HEATER_START[0] && buf[3]==HEATER_START[1])  {StartMessageRepeat =4;} // ответ на команду запуск котла 
   if (buf[2]==0x90)  {StopMessageRepeat=4;} // если получили ответ на команду стоп котла    
   if (buf[2]==0xD6 && buf[3]==0x03)  {DTCareCleared();}  // если получили ответ на команду стирания ошибок                 
   if (buf[2]==0xD6 && buf[3]==0x01)         // если получили ответ на запрос DTC (сообщение с кодами ошибок)
         {
            if (needAction>0 && needAction<NEED_DTCCLEAR) w_bus_init = 14;
            for (byte h = 0; h< sizeof(DTC); h++) DTC[h]=0;
            DTC[0] = buf[4];
            if (buf[4]<=sizeof(DTC)) for (byte h = 0; h< buf[4]; h++) {DTC[h+1]=buf[h*3+5]; bitWrite (DTC[6], h+1,  (buf[h*3+6] & 0x02)>>1);}
         }   

//--------------------------------------------------- котлы EVO (W-BUS 4.x)-------------------------------------
if (WBUS_VER >= 0x40) 
 {
    
     if (buf[2]==0xD0 && buf[3]==0x30)                              // если получили сообщение с текущими данными
   {             
                 if  (buf[4] ==0x0A) { 
                          airfan    = (bool)buf[5];                  // получаем флаг работы нагнетателя воздуха
                          plug      = (buf[5] & 0x02)>>1;            // получаем флаг работы штифта накаливания
                          fuelpump  = (buf[5] & 0x04)>>2;            // получаем флаг работы топливного насоса
                          waterpump = (buf[5] & 0x08)>>3;            // получаем флаг работы циркуляционного насоса
                          blowerfan = (buf[6] & 0x10)>>4;            // получаем флаг работы вентилятора печки автомобиля
                                     }
                   
         if  (buf[6] ==0x0C)  HeaterC = buf[7]-50;                                       // получаем температуру антифриза в котле 
         if  (buf[8]==0x0E) {Vpit = (float)((buf[9]<<8)|buf[10])/1000.0;}                // получаем напряжение борт сети
         if  (buf[11]==0x10) {startWebasto_OK = (bool)buf[12]; last_Flame = currmillis;} // проверяем наличие пламени                                                
         if  (buf[13]==0x12) {PowerHeater = buf[14]/2; }                                 // читаем мощность работы котла                                                
         if  (buf[18]==0x32) {flameout = buf[19];}
         if  (needAction>0 && needAction<NEED_DTCCLEAR) {w_bus_init = 12; sendMessage (HEATER_DTC_REQUEST, sizeof(HEATER_DTC_REQUEST));}
    
    }



 }// end of  котлы EVO (W-BUS 4.x)
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

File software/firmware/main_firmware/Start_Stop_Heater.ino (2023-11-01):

void StartWebasto()
{
 if (ProtocolSTART==IMPULSE)
  {
     digitalWrite (OutWebasto_GndImp, LOW); 
     GND_impulse_timer = 1;
     prevGND_impulse = currmillis;
  }

 else 
  {
     if (ProtocolSTART==STARTBUS) {StartMessageRepeat = 0;  }  else StartMessageRepeat = 4;
     webasto = 1; digitalWrite (OutWebasto_12V, HIGH);
     if (ProtocolSTATUS==STATUSBUS) {TimerVklData = 1; timerVklData = currmillis;}  
     prevWorkCycleHeater=currmillis;
     WorkCycleHeater_timer = true;
     if (!CentrLock) {digitalWrite (PUMPE, 1);Pumpe_timer=0;} // включаем помпу
  }
report = true; prevReport = currmillis;
w_bus_init = 1;

}

void StopWebasto()
{
 if (ProtocolSTART==IMPULSE)
   { 
      digitalWrite (OutWebasto_GndImp, LOW); 
      GND_impulse_timer = 1;
      prevGND_impulse = currmillis;
   }
 else 
   {
      StopMessageRepeat = 0;
      webasto = 0; digitalWrite (OutWebasto_12V, LOW);
      WorkCycleHeater_timer = false;
      if (!CentrLock) {Pumpe_timer=1; prevPumpe = currmillis;} // включаем таймер, по окончании которого помпа выключится
   }
   report = false;
   
   if (ProtocolSTATUS==STATUSBUS) startWebasto_OK = 0;
   smszapusk=0;
}

#ifdef  Signalka
void Start_Engine()
{
 SL_sendcommand (SL_START_ENG);  if (!engine){EngWorkTimer = 1; prevWorkCycleEngine = currmillis;}
}
    #endif

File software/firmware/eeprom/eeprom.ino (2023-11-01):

#include <EEPROM.h>


enum Cells {
ResetNumber_cell,      //0
TimeWebasto_cell,      //1
ProtocolSTART_cell,    //2
StartByte_cell,        //3
ProtocolSTATUS_cell,   //4
HeaterBUS_cell,        //5
WBUS_VER_cell,         //6
delta_cell,            //7
CentrLock_cell,        //8
EngimpTime_cell,       //9
PumpeTime_cell,        //10
sizeNumber_cell,       //11
sizeCells,
TelNumber1_cell =20,  //20
TelNumber2_cell =40,  //40
DallasAddr_cell =60   //60
};


// названия температур котла: 
enum TempC {VyhlopC, EngineC, UlicaC, SalonC, size_arrayTemp};

// возможные протоколы чтения статуса котла:

enum ProtocolSTATUS_ {
   STATUSBUS=1,                 // статусы котла читаются по цифровой шине
   ANALOG                     // статусы котла считываются силами ардуино - по датчикам 
};                   


// возможные протоколы запуска котла:

enum ProtocolSTART_  {
   STARTBUS=1,                  // запуск котла происходит по цифровой шине
   IMPULSE,                   // запуск котла происходит импульсом GND (для подпайки к кнопке пуск на таймере котла)
   POTENCIAL                  // запуск котла происходит подачей потенциала +12В (пока плюс висит - котёл работает)
};        

// возможные типы котла: 

enum Heater_  { TTC_E=1, WBUS, HYDRONIC};                 


//--------------------ниже здесь устанавливаем какие настройки у девайса будут по умолчанию

byte ProtocolSTATUS = STATUSBUS;  // в данном случае статусы читаются по цифровой шине                 
byte ProtocolSTART  = STARTBUS;   // в данном случае запуск котла происходит по цифровой шине                 
byte Heater         = WBUS;       // в данном случае тип шины WBUS
byte StartByte      = 0x20;       // в данном случае байт на старт котла 0x20 (для шины w-bus)
byte worktime       = 30;         // в данном случае время цикла работы котла 30 минут 
byte deltaT         = 45;         // разница температур улицы и выхлопа, выше которой считается, что котёл успешно стартанул

byte sizeTelNumber  = 12;         // количество символов в номере телефона, включая +. Т.е. +79121234567 это будет 12 символов

byte WBUStype  = 0x12;            // версия шины w-bus
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

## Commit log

2023-11-01 First add files
    [WebastoVolkov8_91.drl, WebastoVolkov8_91_copper_bottom.gbr, WebastoVolkov8_91_copper_top.gbr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]
2023-11-01 Updated hardware, bump circuit board to v8.91
    [Ardubasto_CircuitBoard_v8.92.DRL, Ardubasto_CircuitBoard_v8.92_copper_bottom.gbr, Ardubasto_CircuitBoard_v8.92_copper_top.gbr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]
2023-11-03 Updated files, bump circuit board to v8.93
    [Ardubasto_CircuitBoard_v8.93.DRL, Ardubasto_CircuitBoard_v8.93_copper_bottom.gbr, Ardubasto_CircuitBoard_v8.93_copper_top.gbr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]
2023-11-17 Folder movement
    [bottom.STL, top.STL]
